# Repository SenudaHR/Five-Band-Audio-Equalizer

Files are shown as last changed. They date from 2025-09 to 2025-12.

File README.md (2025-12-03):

# 🎶 Five Band Audio Equalizer

## 📌 Introduction
An **audio equalizer** is a circuit that adjusts the output of different frequency bands within an audio signal. Equalizers are widely used in hi-fi systems to achieve superior sound quality across the audible spectrum.  

This project implements a **5-band analog audio equalizer** using operational amplifiers and transistors. After splitting the input signal into five distinct frequency ranges, the circuit applies adjustable gain to each band and displays the levels using sound indicators.

---

## Features

- **Five Frequency Bands:** Custom shaping for Bass, Low-Mid, Mid, High-Mid, and Treble ranges.
- **Analog Signal Path:** All audio processing is analog for true fidelity.
- **Visual Level Metering:** LM3915-based LED VU meter for monitoring output.
- **High-Quality Components:** Uses NE5532 op-amps for low noise and high slew rate.

---

## System Overview

- **Band 1:** Sallen-Key unity-gain low band
- **Bands 2–5:** Cascaded MFB band-pass filter stages
- **Amplification:** NE5532 op-amps in all stages
- **Level Display:** LM3915 IC driving a 10-segment LED bar graph

### Block Diagram

```
[Audio In] --> [Sallen-Key Low Band Filter] --> [MFB Band 2] --> [MFB Band 3] --> [MFB Band 4] --> [MFB Band 5] --> [Summing Amp] --> [Audio Out]
                                                  |
                                            [LM3915 LED Display]
```

---

## Bill of Materials (BOM)

| Component | Quantity | Notes |
|---|---|---|
| NE5532 Op-Amp | Varied | Main filter & amplifier stages |
| LM3915 | 5 | LED VU meter |
| Resistors | Varied | See schematic |
| Capacitors | Varied | See schematic |
| Potentiometers| 6 | Band gain controls |
| LED Bars | 5 | Output display |
| PCB/Perfboard | 4 | For circuit assembly |
| Audio Jacks | 2 | Input/Output |
| Power Supply  | 1 | ±12V or as required by op-amps |

---

## Schematics

You can find the circuit diagram, filter specifications, and layout suggestions [`PCB design`].

---

## Assembly Instructions

1. Connect audio input and output jacks.
2. Double-check all connections for shorts and polarity.
3. Power up and test the circuit with a known audio source.

---

## Usage

- Adjust each potentiometer to boost/cut its associated frequency band.
- Monitor the output signal level using the LED display.
- Fine-tune filter frequencies and Q-factors by changing resistor/cap values (see schematic notes).

---

## Troubleshooting

- **No Output:** Check op-amp power pins, input/output jacks, and signal traces.
- **Distorted Sound:** Ensure proper supply voltage and correct filter component values.
- **LED Meter Not Working:** Verify LM3915 wiring and LED polarity.

---

## Contributing

Pull requests and suggestions are welcome! If you identify issues or want improvements, please open an issue or submit a PR.

---

## Author & Contact

Made by [SenudaHR](https://github.com/SenudaHR)  
For questions, contact via GitHub or open an issue.

---

## References

- Data Sheets: [NE5532](https://www.ti.com/lit/ds/symlink/ne5532.pdf) | [LM3915](https://www.ti.com/lit/ds/symlink/lm3915.pdf)
- Audio Equalizer theory: [Wikipedia](https://en.wikipedia.org/wiki/Equalization_(audio))

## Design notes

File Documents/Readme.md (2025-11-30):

Please open presentation.pdf using Adobe Acrobat and download pcb.mp4 and enclosure.mp4 to the same directory

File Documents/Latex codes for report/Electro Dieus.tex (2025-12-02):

\documentclass{article}
\usepackage{titlesec}
\usepackage[utf8]{inputenc}
\usepackage[a4paper, total={6in, 9in}]{geometry}
\usepackage{fancyhdr}
\usepackage{graphicx} % Add the graphicx package
\usepackage{lipsum} % For placeholder text
\usepackage{tikz}

\usepackage[hidelinks]{hyperref}
\usepackage{wrapfig}
\usepackage{acronym}
\usepackage{float}
\usepackage{multicol}
\usepackage{bm}
\usepackage{circuitikz}
\usetikzlibrary{shapes.geometric}
\usepackage{caption}
\usepackage{acronym}
\usepackage{amsmath,amssymb,amsfonts}
\usepackage{algorithmic}
\usepackage{textcomp}
\usepackage{xcolor}
\usepackage[numbers]{natbib}
\bibliographystyle{ieeetran}
\usepackage{url}
% Set up page headers and footers
\pagestyle{fancy}
\fancyhf{}
\rhead{Electro Dieus}
\lhead{\textit{Five Band Audio Equalizer}}
\cfoot{\thepage}

% Redefine the abstract environment to be single column
\renewenvironment{abstract}
{\par\noindent\textbf{\abstractname}\ \ignorespaces}{\par}

% Redefine section format
\titleformat{\section}
{\normalfont\Large\bfseries}{\thesection}{1em}{}

\begin{document}
	
	% Cover Page
	\begin{titlepage}
		
		\centering
		\vspace*{0.5cm}
		 % Replace with the path to your university logo
		\par\vspace{0.02cm}
		{\fontfamily{lmss}
			{\Large Department of Electronic \& Telecommunication Engineering,\\
				University of Moratuwa, Sri Lanka.}}
		\par\vspace{2cm}
		{\LARGE\bfseries Five Band Audio Equalizer\par}
		\vspace{6cm}
		{\large Group Members:\par}
		\begin{tabular}{l l}
			
			230629R	&	Tennakoon U.G.R.B\\
			230548R 	&	Ratnayake R.M.S.H\\
			230613M	&	Shehan M.N.N \\
			230164K	&	Dissanayake R.K.T\\
			
		\end{tabular}\\
		\vspace{1.5cm}
		{Submitted in partial fulfillment of the requirements for the module\par}
		{EN 2091 Laboratory Practice and Projects\par}
		
		\vspace{1.0cm}
		{ Date: \today}
		\vfill
	\end{titlepage}
	
	\newpage
	
	% Abstract
	\begin{abstract}
		\\
		The \textbf{Five Band Audio Equalizer} is an analog signal processing system designed to modify and enhance audio quality by adjusting the amplitude of distinct frequency bands within an audio signal. The system divides the input audio into five specific frequency ranges---20--300~Hz, 300~Hz--1~kHz, 1--4~kHz, 4--10~kHz, and 10--20~kHz---using precision-designed band-pass filters. Each band can be individually amplified or attenuated through a variable gain control stage, enabling users to shape the tonal balance according to preference or acoustic environment. A preamplifier circuit prepares the signal for processing, while a summing amplifier recombines the adjusted frequency bands to produce a clear and balanced output. Additionally, an \ac{LED}-based level display visually indicates the intensity of each band. The system is implemented using operational amplifiers (NE5532) and the LM3915 display driver, ensuring low noise, high fidelity, and efficient visualization. This project demonstrates practical applications of analog circuit design principles, including filter design, signal amplification, \ac{PCB} layout, and system integration for real-world audio enhancement.
		
	\end{abstract}
	\section*{Abbreviations and Acronyms}
	\begin{acronym}
		\acro{PCB}{Printed Circuit Board}
		\acro{Op Amp}{Operational Amplifier}
		\acro{LED}{Light Emitting Diode}
		\acro{MFB}{Multiple Feedback}
	\end{acronym}
	\newpage
	% Table of Contents
	\tableofcontents
	\newpage
	
	% Sections
	\section{Introduction and Functionality}
	An \textbf{audio equalizer} is a fundamental device used in sound systems to balance and adjust the amplitude of specific frequency components within an audio signal. It enables selective amplification or attenuation of chosen frequency ranges, thereby enhancing tonal quality and the overall listening experience. 
	
	In this project, a \textbf{Five Band Audio Equalizer} was developed using analog electronic circuits to divide the incoming audio signal into five distinct frequency bands:
	\begin{itemize}
		\item 20--300~Hz (Bass range)
		\item 300~Hz--1~kHz (Lower midrange)
		\item 1--4~kHz (Upper midrange)
		\item 4--10~kHz (Presence range)
		\item 10--20~kHz (Treble range)
	\end{itemize}
	
	20-300 Hz frequency band is processed using an unity gain Sallen-Key band-pass filter and other frequency bands processed through \ac{MFB} filter to isolate its respective range. The filtered signals then pass through individual \textbf{gain control stages}, allowing users to adjust amplification levels via variable resistors. The processed signals are subsequently recombined using a \textbf{summing amplifier} to produce a customized and balanced output signal.
	
	A \textbf{pre-amplifier} boosts the input audio signal to the required level, while a \textbf{power amplifier} (based on the LM386 IC) drives the final output with sufficient power. Furthermore, a \textbf{\ac{LED} level indicator} circuit, implemented using the LM3915 \ac{LED} display driver, provides real-time visual feedback of the audio levels across frequency bands. 
	
	Overall, this system integrates the concepts of \textbf{analog filtering}, \textbf{amplification}, and \textbf{signal visualization} into a single compact hardware unit, demonstrating the principles of audio signal processing and analog circuit design in a practical and educational context.

	\section{System Architecture}
	
	\begin{figure}[H]
		\centering
		% Resize to fit page width
		\resizebox{\textwidth}{!}{%
			\begin{tikzpicture}[scale=0.4,transform shape]	% Paths, nodes and wires:
				\node[shape=rectangle, draw, line width=1pt, minimum width=3.715cm, minimum height=1.465cm] at (-26.625, 11.75){} node[anchor=center, align=center, text width=3.327cm, inner sep=6pt] at (-26.625, 11.75){\Large Input Signal};
				\node[shape=rectangle, draw, line width=1pt, minimum width=3.715cm, minimum height=1.465cm] at (-20.125, 11.75){} node[anchor=center, align=center, text width=3.327cm, inner sep=6pt] at (-20.125, 11.75){\large Pre-Amplifier};
				\node[shape=rectangle, draw, line width=1pt, minimum width=4.965cm, minimum height=1.465cm] at (-13.5, 21.25){} node[anchor=center, align=center, text width=4.577cm, inner sep=6pt] at (-13.5, 21.25){\large BPF 20 Hz- 300 Hz};
				\node[shape=rectangle, draw, line width=1pt, minimum width=4.965cm, minimum height=1.465cm] at (-13.5, 11.75){} node[anchor=center, align=center, text width=4.577cm, inner sep=6pt] at (-13.5, 11.75){\large BPF 1 kHz- 4 kHz};
				\node[shape=rectangle, draw, line width=1pt, minimum width=4.965cm, minimum height=1.465cm] at (-13.5, 16.5){} node[anchor=center, align=center, text width=4.577cm, inner sep=6pt] at (-13.5, 16.5){\large BPF 300 Hz- 1 kHz};
				\node[shape=rectangle, draw, line width=1pt, minimum width=4.965cm, minimum height=1.465cm] at (-13.5, 7.25){} node[anchor=center, align=center, text width=4.577cm, inner sep=6pt] at (-13.5, 7.25){\Large BPF 4 kHz- 10 kHz};
				\node[shape=rectangle, draw, line width=1pt, minimum width=4.965cm, minimum height=1.465cm] at (-13.5, 2.5){} node[anchor=center, align=center, text width=4.577cm, inner sep=6pt] at (-13.5, 2.5){\Large BPF 10 kHz- 20 kHz};
				\node[shape=rectangle, draw, line width=1pt, minimum width=4.965cm, minimum height=1.465cm] at (-6.75, 21.25){} node[anchor=center, align=center, text width=4.577cm, inner sep=6pt] at (-6.75, 21.25){\Large Gain Controller};
				\node[shape=rectangle, draw, line width=1pt, minimum width=4.965cm, minimum height=1.465cm] at (-6.5, 16.5){} node[anchor=center, align=center, text width=4.577cm, inner sep=6pt] at (-6.5, 16.5){\Large Gain Controller};
				\node[shape=rectangle, draw, line width=1pt, minimum width=4.965cm, minimum height=1.465cm] at (-6.5, 11.75){} node[anchor=center, align=center, text width=4.577cm, inner sep=6pt] at (-6.5, 11.75){\Large Gain Controller};
				\node[shape=rectangle, draw, line width=1pt, minimum width=4.965cm, minimum height=1.465cm] at (-6.5, 7.25){} node[anchor=center, align=center, text width=4.577cm, inner sep=6pt] at (-6.5, 7.25){\Large Gain Controller};
				\node[shape=rectangle, draw, line width=1pt, minimum width=4.965cm, minimum height=1.465cm] at (-6.5, 2.5){} node[anchor=center, align=center, text width=4.577cm, inner sep=6pt] at (-6.5, 2.5){\Large Gain Controller};
				\node[shape=rectangle, draw, line width=1pt, minimum width=3.715cm, minimum height=1.465cm] at (0.5, 11.75){} node[anchor=center, align=center, text width=3.327cm, inner sep=6pt] at (0.5, 11.75){\LARGE Adder};
				\node[shape=rectangle, draw, line width=1pt, minimum width=3.715cm, minimum height=1.465cm] at (6.125, 11.75){} node[anchor=center, align=center, text width=3.327cm, inner sep=6pt] at (6.125, 11.75){\Large Gain Controller};
				\node[shape=rectangle, draw, line width=1pt, minimum width=3.715cm, minimum height=1.465cm] at (11.5, 11.75){} node[anchor=center, align=center, text width=3.327cm, inner sep=6pt] at (11.5, 11.75){\Large Output Singnal};
				\node[shape=ellipse, draw, line width=1pt, minimum width=1.59cm, minimum height=1.215cm](N1) at (-6.675, 23.192){} node[anchor=center] at (N1.text){$\ac{LED}$};
				\node[shape=ellipse, draw, line width=1pt, minimum width=1.59cm, minimum height=1.215cm](N2) at (-6.5, 18.5){} node[anchor=center] at (N2.text){$\ac{LED}$};
				\node[shape=ellipse, draw, line width=1pt, minimum width=1.59cm, minimum height=1.215cm](N3) at (-6.5, 13.75){} node[anchor=center] at (N3.text){$\ac{LED}$};
				\node[shape=ellipse, draw, line width=1pt, minimum width=1.59cm, minimum height=1.215cm](N4) at (-6.575, 9.058){} node[anchor=center] at (N4.text){$\ac{LED}$};
				\node[shape=ellipse, draw, line width=1pt, minimum width=1.59cm, minimum height=1.215cm](N5) at (-6.5, 4.5){} node[anchor=center] at (N5.text){$\ac{LED}$};
				\draw[-latex] (-24.75, 11.75) -- (-22, 11.75);
				\draw[-latex] (-18.25, 11.75) -- (-16, 11.75);
				\draw[-latex] (-17, 11.75) -- (-17, 7.25) -- (-16, 7.25);
				\draw[-latex] (-17, 7.25) -- (-17, 2.5) -- (-16, 2.5);
				\draw[-latex] (-17, 11.75) -- (-17, 16.5) -- (-16, 16.5);
				\draw[-latex] (-17, 16.5) -- (-17, 21.25) -- (-16, 21.25);
				\draw[-latex] (-11, 21.25) -- (-9.25, 21.25);
				\draw[-latex] (-11, 16.5) -- (-9, 16.5);
				\draw[-latex] (-11, 11.75) -- (-9, 11.75);
				\draw[-latex] (-11, 7.25) -- (-9, 7.25);
				\draw[-latex] (-11, 2.5) -- (-9, 2.5);
				\draw[-latex] (-6.5, 3.25) -- (-6.5, 3.75);
				\draw[-latex] (-6.5, 8) -- (-6.5, 8.5);
				\draw[-latex] (-6.5, 12.5) -- (-6.5, 13.125);
				\draw[-latex] (-6.5, 17.25) -- (-6.5, 17.75) -- (-6.5, 17.875);
				\draw[-latex] (-6.75, 22) -- (-6.75, 22.5);
				\draw[-latex] (-4, 11.75) -- (-1.375, 11.75);
				\draw[-latex] (2.375, 11.75) -- (4.25, 11.75);
				\draw[-latex] (8, 11.75) -- (9.625, 11.75);
				\draw (-4, 2.5) -- (-2, 2.5) -- (-2, 11.75);
				\draw (-4, 7.25) -- (-2, 7.25);
				\draw (-4.25, 21.25) -- (-2, 21.25) -- (-2, 11.75);
				\draw (-4, 16.5) -- (-2, 16.5);
			\end{tikzpicture}
		}
		\caption{Functional Block Diagram}
		\label{fig:Functional Block Diagram}
	\end{figure}

	\subsection{Pre-Amplifier Circuit}
	\begin{figure}[H]
		\centering
		% Resize to fit page width
		\resizebox{0.7\textwidth}{!}{%
			\begin{tikzpicture}[scale=0.7, transform shape]

				% Paths, nodes and wires:
				\draw (-17, 12) -- (-5, 12);
				\draw (-11, 12) to[american resistor, l={$100 k\Omega$}] (-11, 8);
				\draw (-11, 8) to[american resistor, l={$100 k\Omega$}] (-11, 5);
				\draw (-14.202, 8.745) to[american resistor, l={$2.2 k\Omega$}] (-10.202, 8.745);
				\draw (-17, 12) to[capacitor, l={$100 nF$}] (-17, 5);
				\draw (-17, 5) -- (-5, 5);
				\draw (-15.5, 8) to[ecapacitor, l={$4.7 \mu F$}] (-15.5, 5);
				\draw (-13.202, 7.755) to[ecapacitor, l={$1 \mu F$}] (-10.202, 7.755);
				\node[op amp, xscale=1.01, yscale=1.01] at (-9, 8.25){};
				\draw (-6.75, 8.25) to[ecapacitor, l={$10 \mu F$}] (-4.5, 8.25);
				\draw (-7.75, 8.25) -- (-6.75, 8.25);
				\draw (-7, 8.25) -| (-7, 10.25) -- (-7.5, 10.25);
				\draw (-9.75, 10.25) -- (-10.25, 10.25) -- (-10.25, 8.75);
				\draw (-14.202, 8.745) -| (-15.5, 8);
				\draw (-13.342, 7.38) to[currtap, l={$In$}] (-13.342, 8.13);
				\draw (-4.5, 8.75) to[currtap, l={$Out$}] (-4.5, 7.75);
				\draw (-4.5, 7.75) -| (-4.5, 5) -- (-5, 5);
				\draw (-9, 8.75) -- (-9, 12);
				\draw (-9, 7.75) -| (-9, 5);
				\node[ground] at (-9.5, 5){};
				\node[circ] at (-15.5, 5){};
				\node[circ] at (-13.342, 4.999){};
				\node[circ] at (-11, 5){};
				\node[circ] at (-9, 5){};
				\node[circ] at (-4.5, 5){};
				\node[circ] at (-9, 12){};
				\node[circ] at (-11, 12){};
				\node[circ] at (-11, 7.75){};
				\node[circ] at (-10.25, 8.75){};
				\node[circ] at (-7, 8.25){};
				\draw (-7.798, 8.25) -- (-7.75, 8.25);
				\node[shape=rectangle, minimum width=1.965cm, minimum height=0.465cm] at (-4.75, 12.5){} node[anchor=north west, align=left, text width=1.577cm, inner sep=6pt] at (-5.75, 12.75){9 - 30 V};
				\draw (-13.342, 7.38) |- (-13.342, 4.999);
				\draw (-9.75, 10.25) to[american resistor, l={$10 k\Omega$}] (-7.5, 10.25);
			\end{tikzpicture}
		}
		\caption{Pre-Amplifier Circuit}
		\label{fig:Pre-Amplifier Circuit}
	\end{figure}
	
	\subsection{Band Pass Filter Design}
	\begin{multicols}{2}

		\begin{figure}[H]
			\centering
			% Resize to fit page width
			\resizebox{0.5\textwidth}{!}{%
				\begin{tikzpicture}[scale=0.9, transform shape]
					% Paths, nodes and wires:
					\node[op amp] at (-9.06, 2.51){};
					\draw (-15.75, 3) to[american resistor, l={$R_{1}$}] (-12.75, 3);
					\draw (-12.75, 3) to[american resistor, l={$R_{3}$}] (-12.75, -1);
					\draw (-10.25, 4.25) to[american resistor, l={$R_{2}$}] (-6.75, 4.25);
					\draw (-12.75, 3) to[capacitor, l={$C$}] (-10.25, 3);
					\draw (-12.75, 5.25) to[capacitor, l={$C$}] (-9.5, 5.25);
					\draw (-12.75, 3) -| (-12.75, 5.25);
					\draw (-10.25, 4.25) -- (-10.5, 4.25) -| (-10.5, 3);
					\draw (-9.5, 5.25) -- (-6.75, 5.25) -| (-6.75, 2.5) |- (-7.87, 2.51);
					\draw (-10.25, 2.02) -| (-11, -1);
					\node[ground] at (-12.75, -1){};
					\node[ground] at (-11, -1){};
					\node[circ] at (-12.75, 3){};
					\node[circ] at (-10.5, 3){};
					\node[circ] at (-6.75, 4.25){};
					\node[circ] at (-6.75, 2.51){};
					\draw (-6.75, 2.5) -- (-6.25, 2.5);
					\node[ocirc](N1) at (-15.75, 3){} node[anchor=east] at ([xshift=-0.02cm]N1.west){$V_{in}$};
					\node[ocirc](N2) at (-6.25, 2.5){} node[anchor=west] at ([xshift=0.08cm]N2.east){$V_{out}$};
				\end{tikzpicture}
				
			}
			\caption{\ac{MFB} Band-Pass filter}
			\label{fig:MFB Band-Pass filter}
		\end{figure}
		
		\begin{itemize}
			\item Mid-frequency: $f_m = \frac{1}{2\pi C}\sqrt{\frac{R_1+R_3}{R_1R_2R_3}}$
			\item Gain at $f_m$: $-A_m = \frac{R_2}{2R_1}$
			\item Filter quality: $Q = \pi f_m R_2 C$
			\item Bandwidth: $B = \frac{1}{\pi R_2 C}$
		\end{itemize}
	\end{multicols}
	
	The \ac{MFB} band-pass allows to adjust Q, $A_m$, and $f_m$ independently. Bandwidth and gain factor do not depend on $R_3$. Therefore, $R_3$ can be used to modify the mid frequency without affecting bandwidth, B, or gain, $A_m$. Furthermore, 

	\begin{center}
		$R_1 = \frac{R_2}{-2A_m}  ,
		R_2 = \frac{Q}{\pi f_m C}  ,
		R_3 = \frac{-A_m R_1}{2Q^2 + A_m} $
	\end{center}
	
	In order to make Fourth-Order Band-Pass filter, we cascaded two \ac{MFB} Band-Pass filters.\\
	The mid frequency of filter 1 is:
	\begin{equation*}
		f_{m1} = \frac{f_m}{\alpha}
	\end{equation*}
	
	the mid frequency of filter 2 is:
	\begin{equation*}
		f_{m2} = f_m \cdot \alpha 
	\end{equation*}

	with $Q$ being the quality factor of the overall filter.
	
	The individual gain ($A_{mi}$) at the partial mid frequencies, $f_{m1}$ and $f_{m2}$, is the same for both filters:
	\begin{equation*}
		A_{mi} = \frac{Q_i}{Q}\sqrt{\frac{A_m}{B_1}}
	\end{equation*}
	
	\subsubsection*{Unity-Gain Sallen-Key Band-Pass Filter (For 20-300 Hz)}
	\begin{figure}[H]
		\centering
		% Resize to fit page width
		\resizebox{0.9\textwidth}{!}{%
			
			\begin{tikzpicture}[scale=0.6, transform shape]
				% Paths, nodes and wires:
				\node[op amp, yscale=-1] at (-14.81, 4.49){};
				\node[op amp, yscale=-1] at (-6.81, 3.99){};
				\draw (-20, 5) to[american resistor, l={$R_2$}] (-16, 4.98);
				\draw (-19.5, 5) to[american resistor, l={$R_1$}] (-22, 5);
				\draw (-10, 6.5) to[american resistor, l={$R_2^*$}] (-6, 6.5);
				\draw (-9, 4.5) to[american resistor, l={$R_1^*$}] (-9, 0.75);
				\draw (-17.5, 6.5) to[capacitor, l={$C_2$}] (-14.25, 6.5);
				\draw (-16.75, 4) to[capacitor, l={$C_1$}] (-16.75, 1);
				\draw (-13.62, 4.49) to[capacitor, l={$C$}] (-11.25, 4.5);
				\draw (-11.25, 4.5) to[capacitor, l={$C$}] (-9, 4.5);
				\draw (-9, 4.5) -- (-8, 4.5);
				\draw (-11.25, 4.5) -| (-11, 6.5) -- (-10, 6.5);
				\draw (-6, 6.5) -- (-4.75, 6.5) -| (-4.75, 4) |- (-5.62, 3.99);
				\draw (-8, 3.5) -- (-8.25, 3.5) -| (-8.25, 2.25) -| (-4.75, 3.99);
				\draw (-19, 5) -| (-19, 6.5) -- (-17.5, 6.5);
				\draw (-14.25, 6.5) -| (-13.5, 4.5);
				\draw (-16, 4) |- (-16.25, 4) -| (-16.25, 3.25) -- (-13.5, 3.25) -| (-13.5, 4.5);
				\draw (-16.75, 4) -| (-16.75, 5);
				\node[ground] at (-16.75, 1){};
				\node[ground] at (-9, 1){};
				\node[circ] at (-19, 5){};
				\node[circ] at (-16.75, 5){};
				\node[circ] at (-13.5, 4.5){};
				\node[circ] at (-11, 4.5){};
				\node[circ] at (-9, 4.5){};
				\node[circ] at (-4.75, 4){};
				\node[ocirc](N1) at (-22, 5){} node[anchor=east] at (N1.west){$V_{in}$};
				\node[ocirc](N2) at (-3.75, 4){} node[anchor=west] at (N2.east){$V_{out}$};
				\draw (-4.75, 3.99) -| (-3.75, 4);
			\end{tikzpicture}
		}
		\caption{Unity-Gain Sallen-Key Band-Pass Filter}
		\label{fig:Unity-Gain Sallen-Key Band-Pass Filter}
	\end{figure}
	
	{For	given $C_1$ and $C_2$, the resistor values for $R_1$ and $R_2$ are calculated through:
		\[
		R_{1,2} = \frac{a_1 C_2 \mp \sqrt{a_1^2 C_2^2 - 4 b_1 C_1 C_2}}{4 \pi f_c C_1 C_2}
		\]
		For	given $C$, the resistor values for $R_1^*$ and $R_2^*$ are calculated through:
		\[
		R_1^* = \frac{1}{\pi f_c C a_1}
		,
		R_2^* = \frac{a_1}{4 \pi f_c C b_1}	\]}
	
	\subsubsection*{Calculated Theoretical Resistor \& Capacitor Values for Band-pass Filters\footnote{See Appendix \ref{app:practical values} for practical resistor \& capacitor values.}}
	
	\begin{table}[h!]
		\centering
		
		\begin{tabular}{|c|c|c|c|c|c|c|}
			\hline
			$R_1$ & $R_2$ & $C_1$ & $C_2$ &$R_1^*$ & $R_2^*$ & $C$ \\
			\hline
			1.2 k$\Omega$ & 2.2 k$\Omega$ & 220 nF & 470 nF &47 k$\Omega$ & 27 k$\Omega$ & 220 nF \\
			\hline
		\end{tabular}
		\caption{Resistor and Capacitor values (20 Hz – 300 Hz)}
	\end{table}
	\begin{table}[h!]
		\centering
		
		\begin{tabular}{|c|c|c|c|c|}
			\hline
			Frequency Range & $R_1$ & $R_2$ & $R_3$ & $C$ \\
			\hline
			300 Hz – 1 kHz   & 3.3 k$\Omega$ & 10 k$\Omega$ & 3.9 k$\Omega$ & 100 nF \\
			1 kHz – 4 kHz    & 2.7 k$\Omega$ & 8.2 k$\Omega$ & 6.8 k$\Omega$ & 33 nF \\
			4 kHz – 10 kHz   & 2.2 k$\Omega$ & 6.8 k$\Omega$ & 1 k$\Omega$   & 15 nF \\
			10 kHz – 20 kHz  & 2.2 k$\Omega$ & 5.6 k$\Omega$ & 390 $\Omega$  & 10 nF \\
			\hline
		\end{tabular}
		\caption{Resistor and Capacitor values for 1st \ac{MFB} Filter}
	\end{table}
	
	\begin{table}[h!]
		\centering
		
		\begin{tabular}{|c|c|c|c|c|}
			\hline
			Frequency Range & $R_1$ & $R_2$ & $R_3$ & $C$ \\
			\hline
			300 Hz – 1 kHz   & 15 k$\Omega$ & 47 k$\Omega$ & 15 k$\Omega$ & 10 nF \\
			1 kHz – 4 kHz    & 3.3 k$\Omega$ & 10 k$\Omega$ & 6.8 k$\Omega$ & 10 nF \\
			4 kHz – 10 kHz   & 2.7 k$\Omega$ & 8.2 k$\Omega$ & 1 k$\Omega$   & 6.8 nF \\
			10 kHz – 20 kHz  & 1.8 k$\Omega$ & 5.6 k$\Omega$ & 330 $\Omega$  & 6.8 nF \\
			\hline
		\end{tabular}
		\caption{Resistor and Capacitor values for 2nd \ac{MFB} Filter}
	\end{table}

	\subsection{Gain Controller}
	\noindent
	\begin{minipage}{0.48\textwidth}
		\centering
		\begin{circuitikz}
			% Op-amp
			\node[op amp] (opamp) at (0.44, 4.49) {};
			
			% Input resistor
			\draw (-4.5, 5) to[american resistor, l={$R$}] (-0.38, 4.98);
			
			% Feedback resistor (variable)
			\draw (-0.75, 6.25) to[variable american resistor, l={$kR$}] (2.25, 6.25);
			
			% Feedback wiring
			\draw (-0.75, 6.25) -- (-1, 6.25) -| (-1, 5);
			\draw (-0.75, 4) -- (-1, 4) -| (-1, 2.75);
			
			% Output connection
			\draw (1.63, 4.49) -| (2.5, 4.5) -- (2.5, 6.25) -- (2.25, 6.25);
			
			% Input/output nodes
			\node[ocirc](N1) at (-4.5, 5){} node[anchor=east] at (N1.west){$V_{in}$};
			\draw (2.5, 4.49) -| (2.75, 4.5);
			\node[ocirc](N2) at (2.75, 4.49){} node[anchor=west] at (N2.east){$V_{out}$};
			
			% Ground and connection dots
			\node[circ] at (-1, 5) {};
			\node[circ] at (2.5, 4.5) {};
			\node[ground] at (-1, 2.75) {};
		\end{circuitikz}
		\captionof{figure}{Gain Controller}
		\label{fig:GainController}
	\end{minipage}%
	\hfill
	\begin{minipage}{0.48\textwidth}
		\[
		\frac{V_{in}-0}{R} = \frac{0 - V_{out}}{kR}
		\]
		\[
		V_{out} = -kV_{in}
		\]
	\end{minipage}
	\subsection{Adder \& Gain Controller}
	\noindent
	\begin{minipage}{0.48\textwidth}
		\centering
		\begin{circuitikz}[scale=0.9,transform shape]
			% Paths, nodes and wires:
			\node[op amp] at (0.44, 4.49){};
			\draw (-0.75, 6.25) to[variable american resistor, l={$kR$}] (2.25, 6.25);
			\draw (-0.75, 6.25) -- (-1, 6.25) -| (-1, 5);
			\draw (-0.75, 4) -- (-1, 4) -| (-1, 2.75);
			\draw (1.63, 4.49) -| (2.5, 4.5) -- (2.5, 6.25) -- (2.25, 6.25);
			\draw (2.5, 4.49) -| (2.75, 4.5);
			\node[ocirc](N1) at (2.75, 4.49){} node[anchor=west] at (N1.east){$V_{out}$};
			\node[circ] at (-1, 5){};
			\node[circ] at (2.5, 4.5){};
			\node[ground] at (-1, 2.75){};
			\draw (-0.75, 4.98) |- (-1, 5) -- (-1.75, 5) -- (-2.5, 5) -| (-2.5, 6.5) -- (-2.5, 3.25);
			\draw (-6, 6.5) to[american resistor, l={$R$}] (-2.5, 6.5);
			\draw (-6, 5.5) to[american resistor, l={$R$}] (-2.5, 5.5);
			\draw (-6, 4.5) to[american resistor, l={$R$}] (-2.5, 4.5);
			\draw (-6, 3.5) to[american resistor, l={$R$}] (-2.5, 3.5);
			\draw (-6, 2.5) to[american resistor, l={$R$}] (-2.5, 2.5);
			\draw (-2.5, 3.25) -| (-2.5, 2.5);
			\node[ocirc](N2) at (-6, 6.5){} node[anchor=east] at (N2.west){$V_1$};
			\node[ocirc](N3) at (-6, 5.5){} node[anchor=east] at (N3.west){$V_2$};
			\node[ocirc](N4) at (-6, 4.5){} node[anchor=east] at (N4.west){$V_3$};
			\node[ocirc](N5) at (-6, 3.5){} node[anchor=east] at (N5.west){$V_4$};
			\node[ocirc](N6) at (-6, 2.5){} node[anchor=east] at (N6.west){$V_5$};
			\node[circ] at (-2.5, 5.5){};
			\node[circ] at (-2.5, 4.5){};
			\node[circ] at (-2.5, 3.5){};
		\end{circuitikz}
		
		\captionof{figure}{Adder and Gain Controller}
		\label{fig:Adder and Gain Controller}
	\end{minipage}%
	\hfill
	\begin{minipage}{0.4\textwidth}
		
		\[ \sum_{i=1}^{5} \frac{V_i-0}{R} = \frac{0-V_{out}}{kR}
		\]
		\[V_{out}=-k\sum_{i=1}^{5} V_{i}
		\]
		
	\end{minipage}
	
	\subsection{\ac{LED} Display}
	
	\begin{figure}[H]
		\centering
		
		\caption{Circuit connection for \ac{LED} display}
		\label{fig:led}
	\end{figure}
	
	\subsection{Power Amplifier Circuit}
	\begin{figure}[H]
		\centering
		% Resize to fit page width
		\resizebox{0.9\textwidth}{!}{%
			\begin{tikzpicture}[scale=0.6, transform shape]
				% Paths, nodes and wires:
				% Paths, nodes and wires:
				\node[op amp, xscale=1.55, yscale=-1.55](N1) at (-6.156, 4.509){} node[anchor=center] at (N1.text){$LM386$};
				\draw (1, 4.5) to[loudspeaker, l={8 $\Omega$, 0.5 W}] (1, 2.25);
				\draw (-12, 6.75) to[american resistor] (-12, 3.75);
				\draw (-3, 4.5) to[american resistor, l={$10\Omega$}] (-3, 2);
				\draw (-6.285, 7.845) to[american resistor, l={$1.2 k\Omega$}] (-6.285, 5.345);
				\draw (-3, 2) to[capacitor, l={$100 nF$}] (-3, 0);
				\draw (-5.285, 6.595) to[ecapacitor, l={$10\mu F$}] (-5.285, 4.845);
				\draw (-2.5, 4.5) to[ecapacitor, l={$220 \mu F$}] (-0.25, 4.5);
				\draw (-12, -0) -- (1, -0) -| (1, 2.25);
				\draw (1, 4.5) -- (-0.25, 4.5);
				\draw (-2.5, 4.5) |- (-4.311, 4.51);
				\draw (-6.285, 7.845) -- (-5.285, 7.845) -| (-5.285, 6.595);
				\draw (-7, 5.75) -| (-7, 8);
				\draw (-7, 3.25) -| (-7, -0);
				\draw (-8, 3.75) -| (-8, -0);
				\draw (-12, 6.75) -- (-13, 6.75);
				\draw (-12, 3.75) -| (-12, -0);
				\node[ground] at (-7, -0){};
				\draw[-latex] (-8, 5.269) -- (-12, 5.269);
				\node[ocirc](N2) at (-13, 6.75){} node[anchor=east] at (N2.west){$Input$};
				\node[ocirc] at (-13, -0){};
				\node[circ] at (-12, -0){};
				\node[circ] at (-8, -0){};
				\node[circ] at (-7, -0){};
				\node[circ] at (-3, -0){};
				\node[circ] at (-3, 4.5){};
				\node[plain crossing](N3) at (-7, 8){} node[anchor=south] at (N3.north){$+ V_{CC}$};
				\draw (-12, -0) -- (-13, -0);
				\node[ocirc](N4) at (-6.285, 5.345){} node[anchor=north] at (N4.south){$1$};
				\node[ocirc](N5) at (-5.25, 4.75){} node[anchor=east] at (N5.text){$8$};
				\draw (-5.267, 4.692) -| (-5.285, 4.845);
			\end{tikzpicture}
		}
		\caption{Power Amplifier Circuit}
		\label{fig:Power Amplifier Circuit}
	\end{figure}

	\section{Component Selection (Main electronic components)}
	
	\begin{enumerate}
		\item\textbf{NE5532 Operational Amplifier}
		\begin{itemize}
			
			\item \textbf{Low Noise}: 5\,nV/$\sqrt{\text{Hz}}$ suitable for high-fidelity audio
			\item \textbf{Bipolar Input}: Ensures low offset and distortion in precision audio
			\item \textbf{Dual Channel}: Two \ac{Op Amp} per IC for compact design
			\item \textbf{High Slew Rate}: 9\,V/$\mu$s supports wide dynamic range
			\item \textbf{Wide Bandwidth}: 10\,MHz gain-bandwidth product for audio applications
			\item \textbf{Wide Supply}: $\pm3$\,V to $\pm20$\,V operation for design flexibility
			\item \textbf{High Drive Capability}: Can directly drive 600\,$\Omega$ loads
		\end{itemize}
		\item \textbf{LM3915 Dot/Bar Display Driver}
		\begin{itemize}
			\item Logarithmic 3 dB/step response for audio
			\item Direct \ac{LED} drive without current-limiting resistors
			\item Simple setup with minimal external components
			\item Over-voltage protection ($\pm$35V) on input
		\end{itemize}

	\end{enumerate}	

	\begin{minipage}[t]{0.48\textwidth}
		\centering
		
		\captionof{figure}{NE5532P Operational Amplifier}
	\end{minipage}
	\hfill
	\begin{minipage}[t]{0.48\textwidth}
		\centering
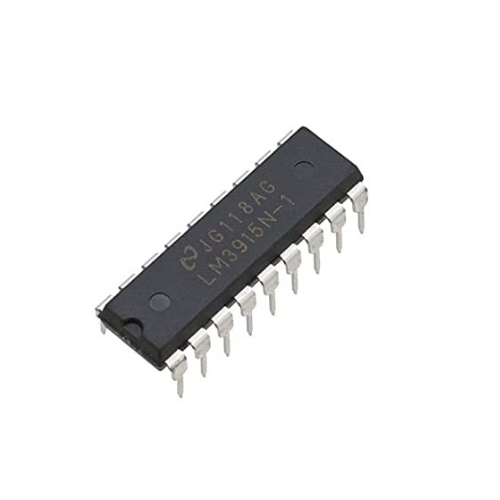
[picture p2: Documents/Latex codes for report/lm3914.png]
		
		\captionof{figure}{LM3915 Dot/Bar Display Driver}
	\end{minipage}

	\section{\ac{PCB} Design}
	We designed 4 separate \ac{PCB}s using Altium Designer. (Why 4 \ac{PCB}s?\footnote{See Appendix \ref{app:PCB Schematics}.})
	\begin{multicols}{2}
		\begin{figure}[H]
			\centering
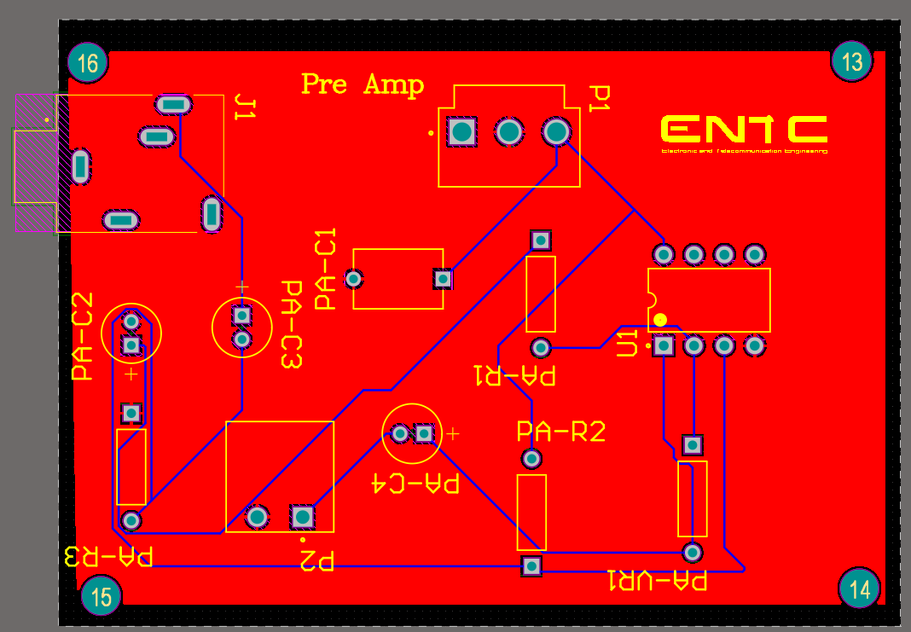
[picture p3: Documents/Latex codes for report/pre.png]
			
			\caption{2D pathway of Pre Amplifier Circuit}
			\label{fig:pre}
		\end{figure}
		\begin{figure}[H]
			\centering
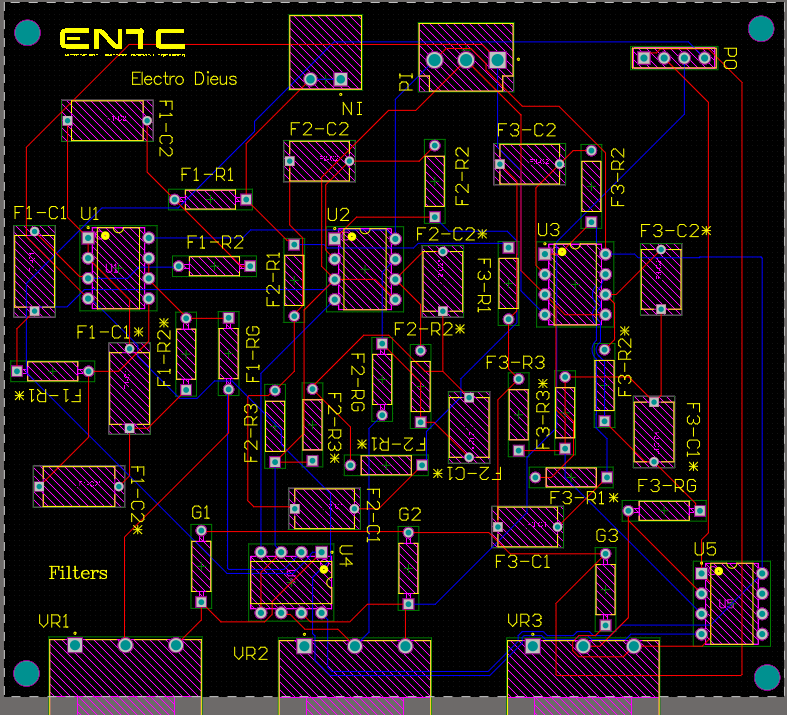
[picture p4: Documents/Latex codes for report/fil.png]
			
			\caption{2D pathway of Filter Circuit}
			\label{fig:fil}
		\end{figure}
		\begin{figure}[H]
			\centering
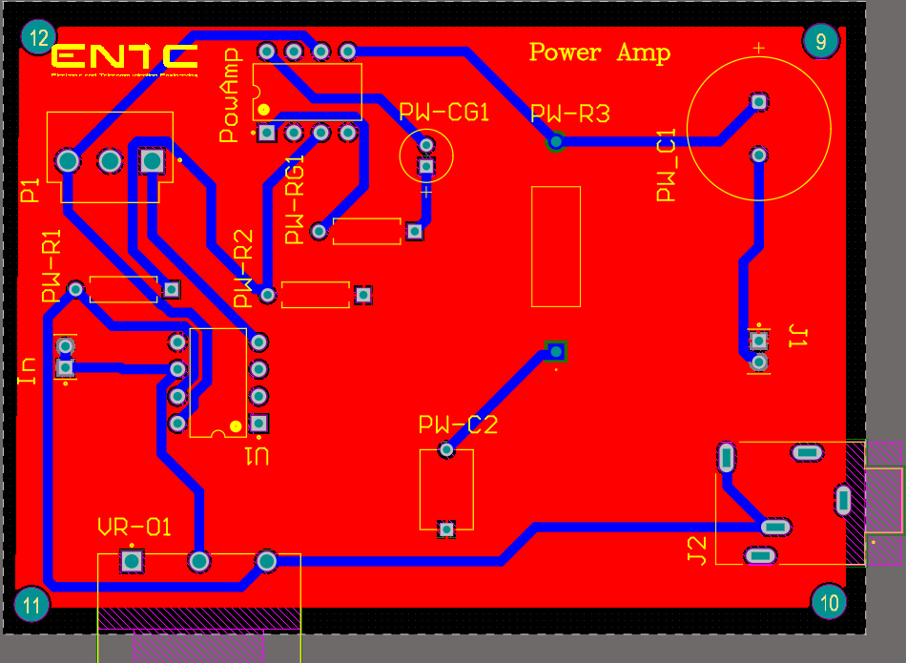
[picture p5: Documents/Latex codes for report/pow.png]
			
			\caption{2D pathway of Power Amplifier Circuit}
			\label{fig:pow}
		\end{figure}
		\begin{figure}[H]
			\centering
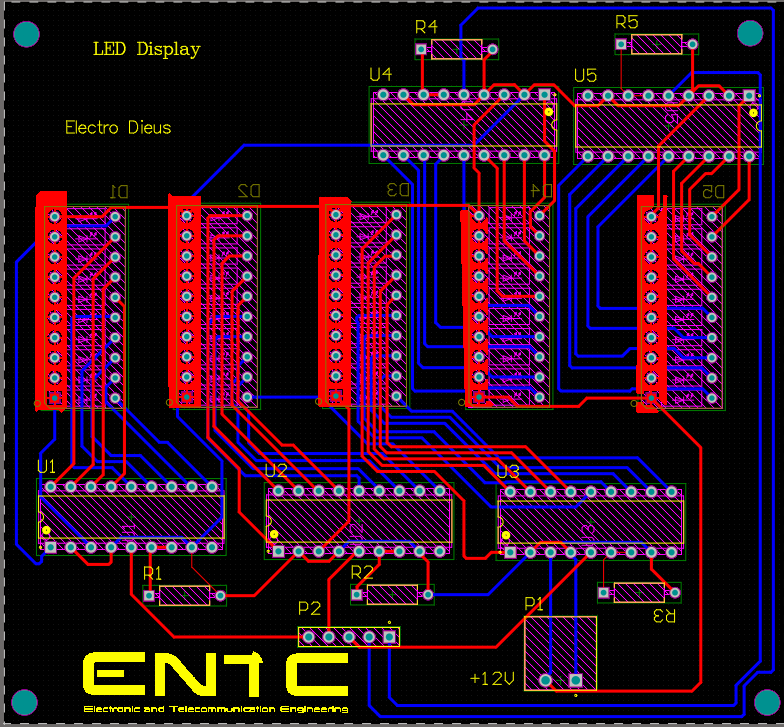
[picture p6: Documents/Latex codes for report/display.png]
			
			\caption{2D pathway of \ac{LED} Display Circuit}
			\label{fig:display}
		\end{figure}
		
	\end{multicols}
	\begin{figure}[H]
		\centering
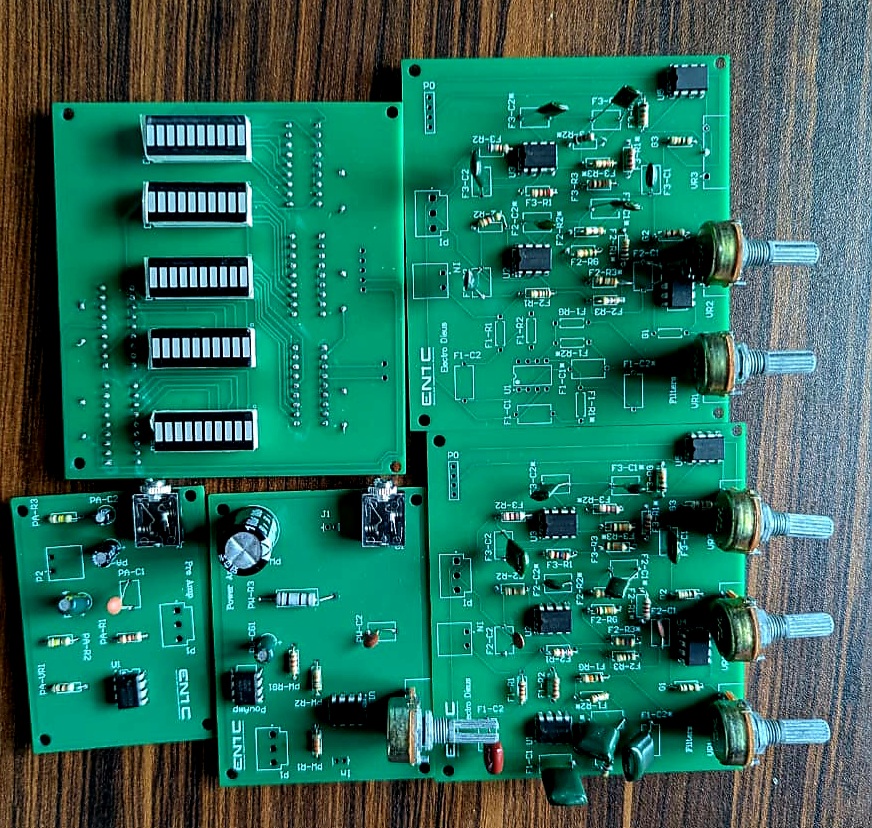
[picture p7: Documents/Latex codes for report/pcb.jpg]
		
		\caption{Soldered \ac{PCB}s}
		\label{fig:pcb}
	\end{figure}

	\section{Enclosure Design}
	
	\begin{multicols}{2}
		\begin{figure}[H]
			\centering
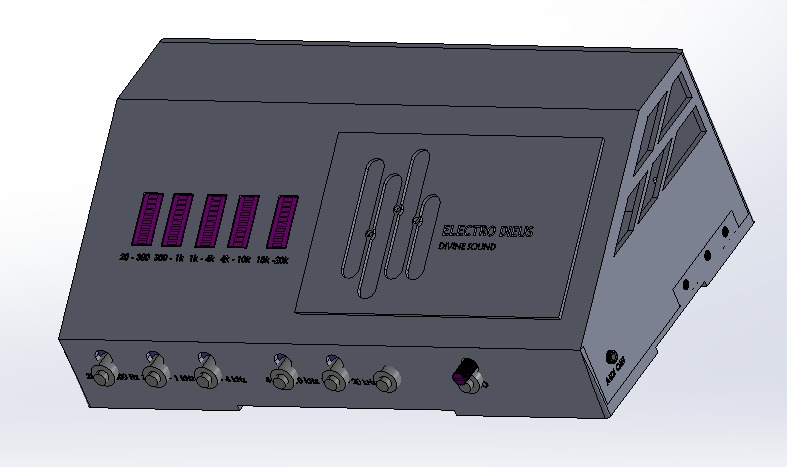
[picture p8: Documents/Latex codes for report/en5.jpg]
			
			\caption{Enclosure front view}
			\label{fig:Enclosure front view}
		\end{figure}
		\begin{figure}[H]
			\centering
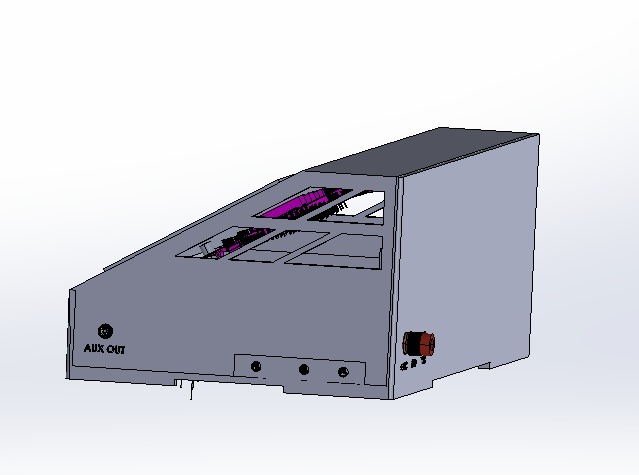
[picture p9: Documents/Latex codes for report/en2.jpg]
			
			\caption{Right side view}
			\label{fig:Side view1}
		\end{figure}
		\begin{figure}[H]
			\centering
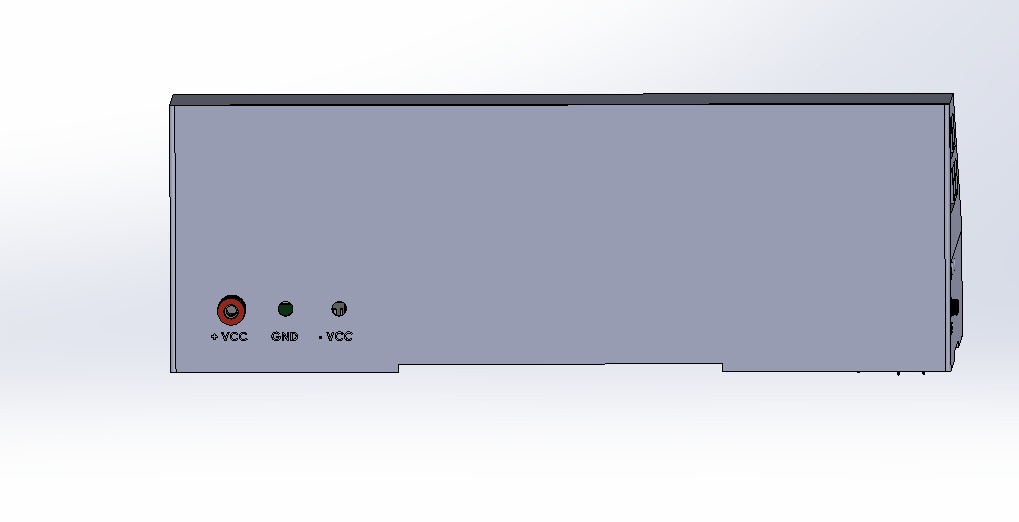
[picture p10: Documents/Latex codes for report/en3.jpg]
			
			\caption{Back view}
			\label{fig:Back view}
		\end{figure}
		\begin{figure}[H]
			\centering
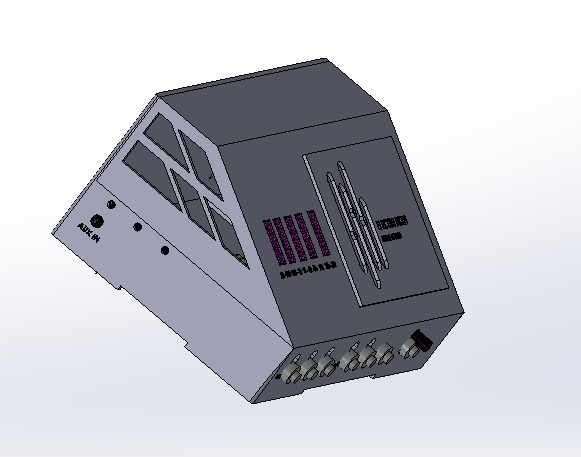
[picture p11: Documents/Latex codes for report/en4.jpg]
			
			\caption{Left side view}
			\label{fig:Left side view}
		\end{figure}
	\end{multicols}
    \begin{figure}[H]
        \centering
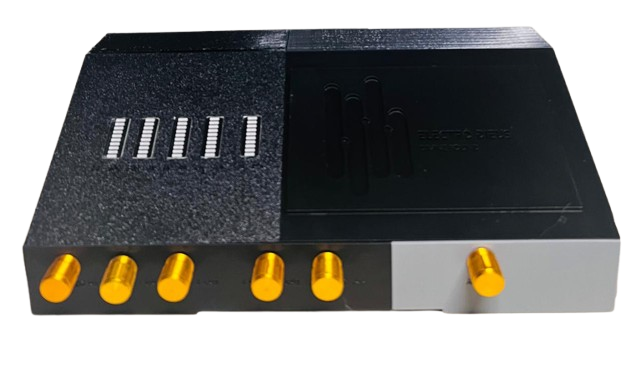
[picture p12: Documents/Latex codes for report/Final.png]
        
        \caption{Final product}
        \label{fig:placeholder}
    \end{figure}
	
	\newpage
	\section{Software Simulation and Hardware Testing}
	\subsection{Software Simulation (Using LTspice)}
	
	\begin{figure}[H]	\centering
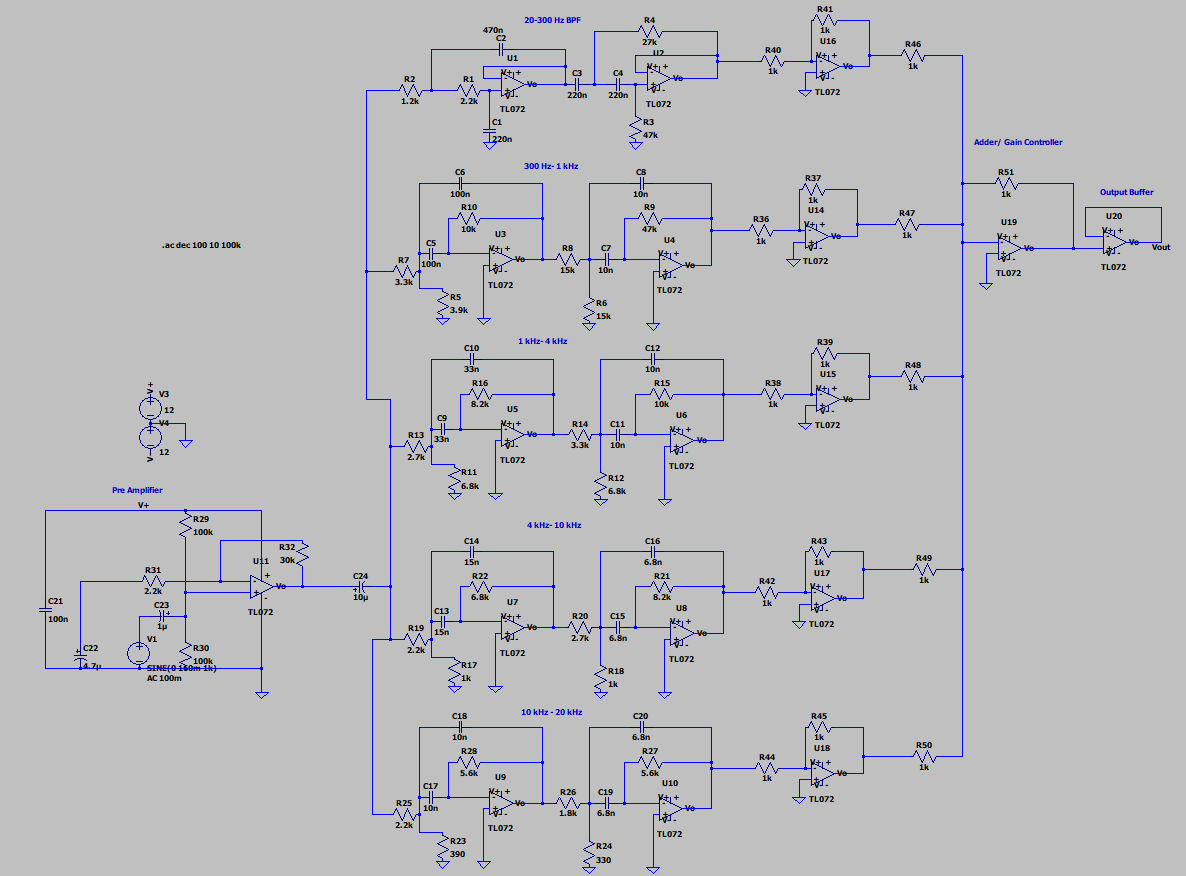
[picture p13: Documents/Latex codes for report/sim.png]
		
		\caption{Circuit Diagram}
		\label{fig:sim}
	\end{figure}
	\begin{figure}[H]
		\centering
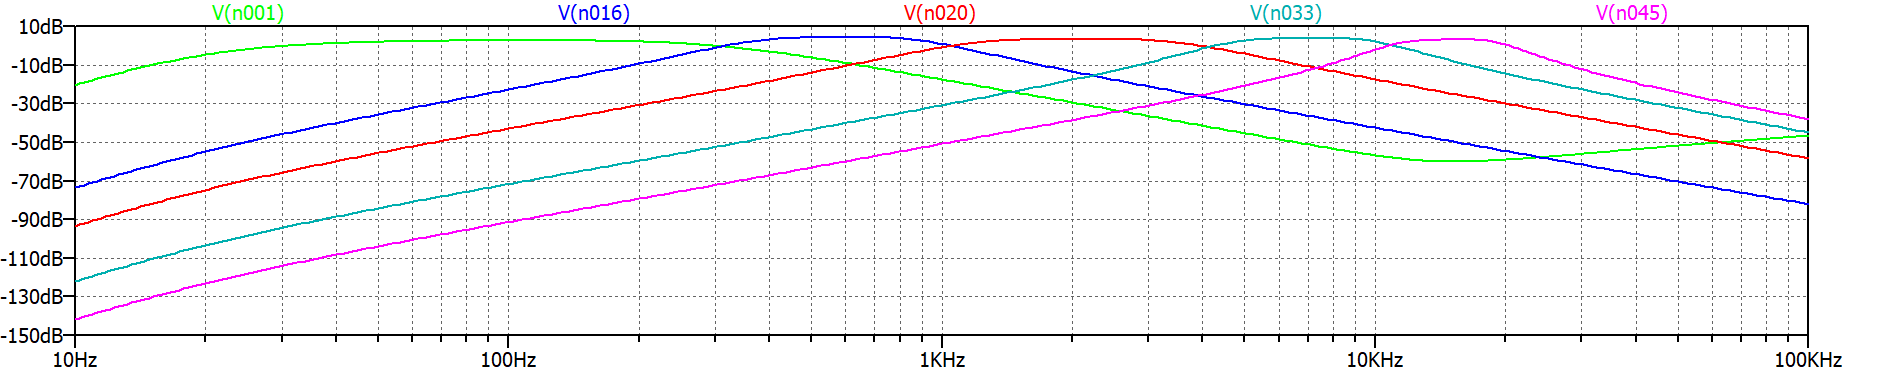
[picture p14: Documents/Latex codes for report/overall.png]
		
		\caption{Frequency Response of Each Filter}
		\label{fig:Frequency Response of Each Filter}
	\end{figure}
	\begin{figure}[H]
	
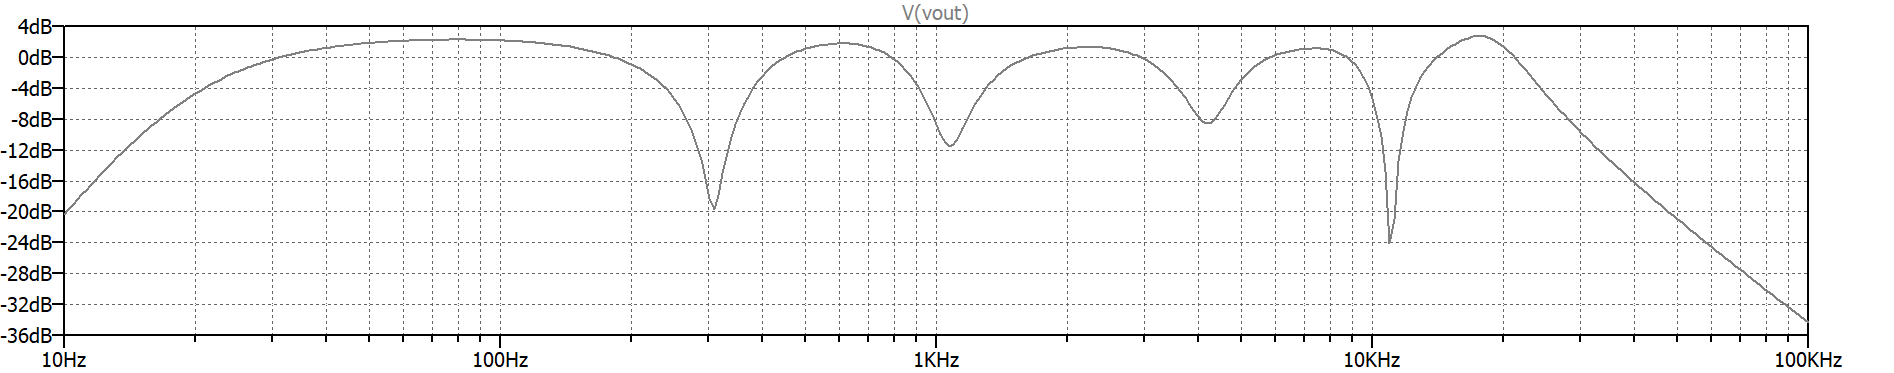
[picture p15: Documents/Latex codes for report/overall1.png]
		
		\caption{Overall Frequency Response}
		\label{fig:overall1}
	\end{figure}

	\subsection{Hardware Testing}
	\begin{multicols}{2}
		\begin{figure}[H]
			\centering
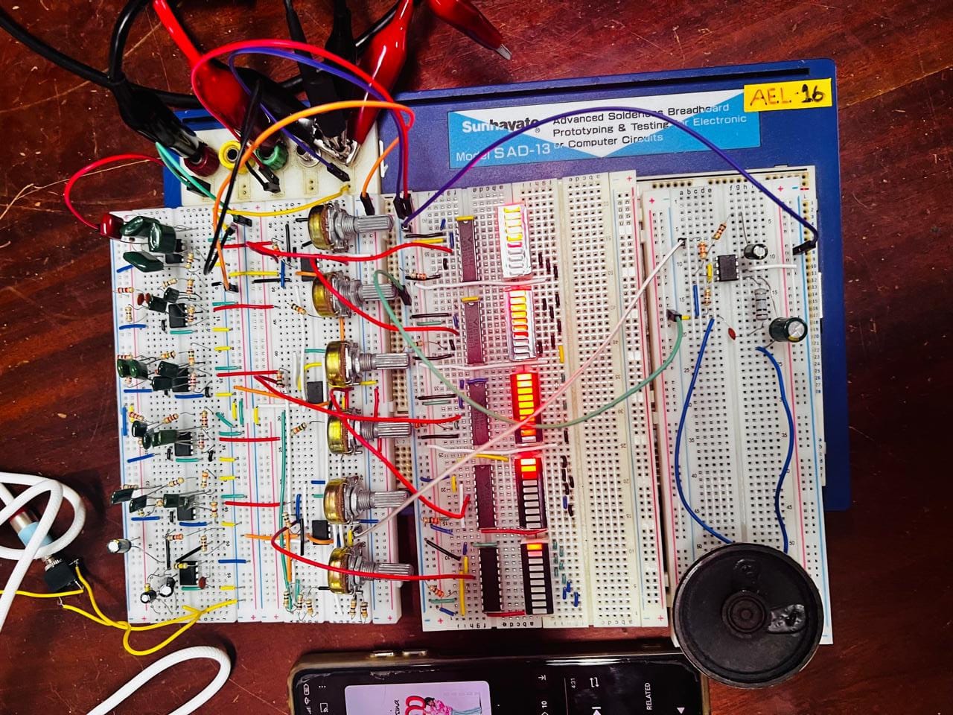
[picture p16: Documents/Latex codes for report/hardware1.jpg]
			
			\caption{Breadboard implementation}
			\label{fig:hardware}
		\end{figure}
		\begin{figure}[H]
			\centering
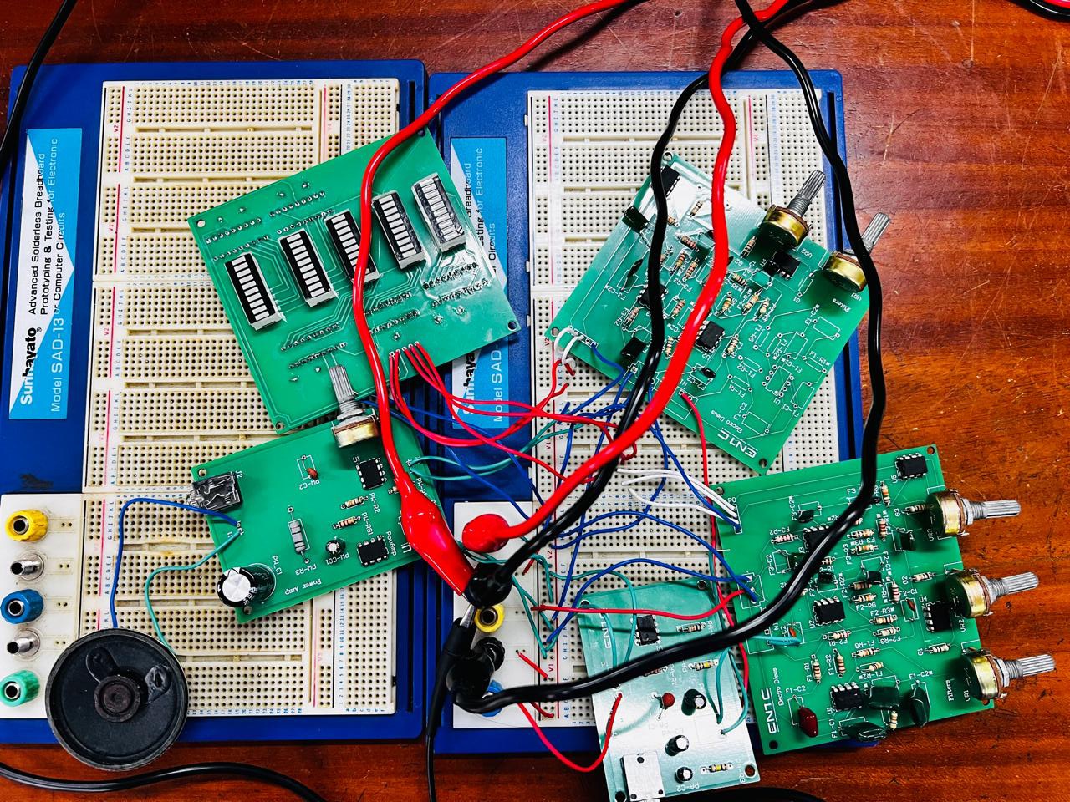
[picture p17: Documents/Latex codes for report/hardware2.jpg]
			
			\caption{\ac{PCB} testing}
			\label{fig:harware2}
		\end{figure}
	\end{multicols}

	\section{Conclusion \& Future Works}
	The \textbf{Five Band Audio Equalizer} successfully achieves its primary objective of dividing an input audio signal into five distinct frequency bands and allowing individual gain control for each band. Through the integration of pre-amplifier, band-pass filter, gain control, adder, and power amplifier stages, the system provides a fully analog audio equalization platform with real-time visual feedback using an \ac{LED} display. The implemented filters effectively cover the entire audible range from 20~Hz to 20~kHz, enabling fine-tuned tonal adjustment and improved sound clarity. Experimental testing confirmed that the circuit delivers stable operation with low distortion and noise, demonstrating the effectiveness of the NE5532 \ac{Op Amp} and LM3915 \ac{LED} display driver in high-fidelity analog applications.
	
	\textbf{Future development} of the project can focus on several enhancements. Firstly, the system can be expanded into a \textbf{stereo equalizer} by duplicating the current design for left and right audio channels, enabling complete two-channel sound processing for improved spatial audio experience. Secondly, designing a dedicated \textbf{power supply unit} with voltage regulation and filtering will ensure stable performance and minimize noise interference. Additional improvements could include integrating tone presets, miniaturized \ac{PCB} layouts, and incorporating protection circuits to increase durability and user convenience. These developments would transform the prototype into a fully functional and reliable consumer-grade audio equalizer system.

	\section{Contribution of Group Members}
	\begin{tabular}{|l|p{9cm}|} % p{6cm} allows auto line wrapping
		\hline
		\textbf{Student's Name (Index No.)} & \textbf{Contribution} \\
		\hline
		Tennakoon U.G.R.B. (230629R) & Filter calculations, \ac{PCB} design, Testing \& debugging, Soldering \\
		\hline
		Ratnayake R.M.S.H. (203548R) & \ac{PCB} design, Circuits design, Circuits simulation, Soldering \\
		\hline
		Shehan M.N.N. (230613M) & Breadboard implementation, Enclosure Design, Testing \\
		\hline
		Dissanayake R.K.T. (230164K) &  \ac{LED} display circuit design \& breadboard implementation, Testing, Assembling \\
		\hline
	\end{tabular}

	\section*{Acknowledgment}
	
	We would like to express our sincere gratitude to \textbf{Mr. Chanula Luckshan}, our project supervisor, for his continuous guidance and support throughout the development of the \textit{Five Band Audio Equalizer} project. His valuable suggestions at the early stages of circuit design and his assistance in identifying and correcting errors during \ac{PCB} and enclosure design were instrumental in achieving a successful outcome.
	
	We also wish to extend our appreciation to \textbf{Dr. Pranjeevan Kulasingham}, our Signals and Systems lecturer, for providing us with a comprehensive understanding of analog filter design principles, which formed the foundation for our filter implementation in this project.
	
	Our heartfelt thanks go to \textbf{Dr. Sampath Perera}, the module coordinator of EN2091 Laboratory Practice and Projects, for his overall supervision, encouragement, and for providing the necessary resources to complete this project effectively.
	
	Finally, we would like to acknowledge the support of all the \textbf{laboratory assistants} of the Department of Electronic and Telecommunication Engineering for their technical help, timely guidance, and assistance during the hardware testing and implementation stages.
	
	\begin{thebibliography}{1}
		\bibitem{TI2002}
		Texas Instruments, \emph{op Amps for Everyone Design Guide}, Rev. 8, Advanced Analog Products, SLOD006B, Aug. 2002. [Online]. Available: https://web.mit.edu/6.101/www/reference/op\_amps\_everyone.pdf
		
		\bibitem{TI:NE5532}
		Texas Instruments, “NE5532 — Dual, 30-V, 10-MHz, low-noise operational amplifier for audio applications,”  
		TI product page (Datasheet Rev. J), Jan. 27, 2015.  
		[Online]. Available: \url{https://www.ti.com/product/NE5532}  
		\bibitem{lm3915_datasheet}
		Texas Instruments. \emph{LM3915 Dot/Bar Display Driver Datasheet}, SNVS740C. Revised Mar. 2013. [Online]. Available: \url{https://www.alldatasheet.com/datasheet-pdf/view/558236/TI/LM3915.html}
		
		\bibitem{HomemadeCircuitsOpAmp}
		``Op Amp Preamplifier Circuits – For MICs, Guitars, Pick-ups, Buffers." \emph{Homemade Circuits}. Last Updated: Sept. 13, 2023. Available: \url{https://www.homemade-circuits.com/op-amp-preamplifier-circuits-for-mics-guitars-pick-ups-as-buffer/} 
		
		\bibitem{GaraipoomLM386}
		A. Garaipoom, ``LM386 Audio Amp Circuit – Build Small, Loud \& Battery-Friendly!," \emph{ElecCircuit.com}. Last Updated: Sept. 17, 2025. Available: \url{https://www.eleccircuit.com/lm386-audio-amplifier-circuit/} 
	\end{thebibliography}
	
	\newpage
	\section*{Appendix}
	\appendix
	
	\section{Practical Resistor \& Capacitor Values}\label{app:practical values}
	
	\begin{table}[h!]
		\centering
		
		\begin{tabular}{|c|c|c|c|c|c|c|}
			\hline
			$R_1$ & $R_2$ & $C_1$ & $C_2$ &$R_1^*$ & $R_2^*$ & $C$ \\
			\hline
			1.2 k$\Omega$ & 2.2 k$\Omega$ & 220 nF & 470 nF &47 k$\Omega$ & 27 k$\Omega$ & 220 nF \\
			\hline
		\end{tabular}
		\caption{Resistor and Capacitor values (20 Hz – 300 Hz)}
	\end{table}
	\begin{table}[h!]
		\centering
		
		\begin{tabular}{|c|c|c|c|c|}
			\hline
			\textbf{Frequency Range} & $R_1$ & $R_2$ & $R_3$ & $C$ \\ \hline
			300 Hz -- 1 kHz   & $2.7\,\text{k}\Omega$ & $10\,\text{k}\Omega$ & $10\,\text{k}\Omega$ & $100\,\text{nF}$ \\ \hline
			1 kHz -- 4 kHz    & $2.7\,\text{k}\Omega$ & $8.2\,\text{k}\Omega$ & $15\,\text{k}\Omega$ & $33\,\text{nF}$ \\ \hline
			4 kHz -- 10 kHz   & $2.2\,\text{k}\Omega$ & $6.8\,\text{k}\Omega$ & $1.2\,\text{k}\Omega$ & $15\,\text{nF}$ \\ \hline
			10 kHz -- 20 kHz  & $1.8\,\text{k}\Omega$ & $5.6\,\text{k}\Omega$ & $470\,\Omega$ & $10\,\text{nF}$ \\ \hline
		\end{tabular}
		\caption{Resistor and Capacitor values for 1st \ac{MFB} Filter}
	\end{table}
	\begin{table}[h!]
		\centering
		
		\begin{tabular}{|c|c|c|c|c|}
			\hline
			\textbf{Frequency Range} & $R_1$ & $R_2$ & $R_3$ & $C$ \\ \hline
			300 Hz -- 1 kHz   & $8.2\,\text{k}\Omega$ & $27\,\text{k}\Omega$ & $27\,\text{k}\Omega$ & $10\,\text{nF}$ \\ \hline
			1 kHz -- 4 kHz    & $2.2\,\text{k}\Omega$ & $8.2\,\text{k}\Omega$ & $15\,\text{k}\Omega$ & $10\,\text{nF}$ \\ \hline
			4 kHz -- 10 kHz   & $2.2\,\text{k}\Omega$ & $6.8\,\text{k}\Omega$ & $1.2\,\text{k}\Omega$ & $6.8\,\text{nF}$ \\ \hline
			10 kHz -- 20 kHz  & $1.5\,\text{k}\Omega$ & $3.9\,\text{k}\Omega$ & $390\,\Omega$ & $6.8\,\text{nF}$ \\ \hline
		\end{tabular}
		\caption{Resistor and Capacitor values for 2nd \ac{MFB} Filter}
	\end{table}
	\section{\ac{PCB} Schematics}\label{app:PCB Schematics}
    \subsection*{\ac{PCB} Partitioning as a Cost-Reduction Strategy}

The initial hardware implementation consisted of two printed circuit boards (\ac{PCB}s): a main circuit \ac{PCB} measuring 162.94~mm~$\times$~112.52~mm and a display \ac{PCB} measuring 119.63~mm~$\times$~58.67~mm. The total estimated manufacturing cost for this configuration was approximately \$20. 

To minimize fabrication costs, the final design was divided into four smaller modular \ac{PCB}s, each with dimensions below 100~mm~$\times$~100~mm. This allowed the design to qualify for low-cost prototyping services offered by \ac{PCB} manufacturers. Consequently, the total fabrication cost was reduced to \$8 (four boards at \$2 each). This partitioning approach resulted in a \textbf{60\% reduction in manufacturing cost}, achieved without compromising system functionality or performance.

    \begin{figure}[H]
        \centering
        
        \caption{Pre-Amplifer \& Filters }
        \label{fig:placeholder}
    \end{figure}
      \begin{figure}[H]
        \centering
        
        \caption{Power Amplifier \& Display}
        \label{fig:placeholder1}
    \end{figure}
	
\end{document}

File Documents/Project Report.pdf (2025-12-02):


Department of Electronic & Telecommunication Engineering, University of Moratuwa, Sri Lanka.

# Five Band Audio Equalizer

Group Members:
230629R | Tennakoon U.G.R.B
230548R | Ratnayake R.M.S.H
230613M | Shehan M.N.N
230164K | Dissanayake R.K.T

Submitted in partial fulfillment of the requirements for the module EN 2091 Laboratory Practice and Projects

Date: December 2, 2025

Five Band Audio Equalizer | Electro Dieus

Abstract
The Five Band Audio Equalizer is an analog signal processing system designed to modify and enhance audio quality by adjusting the amplitude of distinct frequency bands within an audio signal. The system divides the input audio into five specific frequency ranges—20–300 Hz, 300 Hz–1 kHz, 1–4 kHz, 4–10 kHz, and 10–20 kHz—using precision-designed band-pass filters. Each band can be individually amplified or attenuated through a variable gain control stage, enabling users to shape the tonal balance according to preference or acoustic environment. A preamplifier circuit prepares the signal for processing, while a summing amplifier recombines the adjusted frequency bands to produce a clear and balanced output. Additionally, an Light Emitting Diode (LED)-based level display visually indicates the intensity of each band. The system is implemented using operational amplifiers (NE5532) and the LM3915 display driver, ensuring low noise, high fidelity, and efficient visualization. This project demonstrates practical applications of analog circuit design principles, including filter design, signal amplification, Printed Circuit Board (PCB) layout, and system integration for real-world audio enhancement.

## Abbreviations and Acronyms

PCB Printed Circuit Board

Op Amp Operational Amplifier

LED Light Emitting Diode

MFB Multiple Feedback

1

## Contents

1 Introduction and Functionality | 3
2 System Architecture | 3
3 Component Selection (Main electronic components) | 7
4 PCB Design | 8
5 Enclosure Design | 9
6 Software Simulation and Hardware Testing | 10
7 Conclusion & Future Works | 11
8 Contribution of Group Members | 12
A Practical Resistor & Capacitor Values | 13
B PCB Schematics | 13

2

## 1 Introduction and Functionality

An audio equalizer is a fundamental device used in sound systems to balance and adjust the amplitude of specific frequency components within an audio signal. It enables selective amplification or attenuation of chosen frequency ranges, thereby enhancing tonal quality and the overall listening experience.
In this project, a Five Band Audio Equalizer was developed using analog electronic circuits to divide the incoming audio signal into five distinct frequency bands:
- 20–300 Hz (Bass range)
- 300 Hz–1 kHz (Lower midrange)
- 1–4 kHz (Upper midrange)
- 4–10 kHz (Presence range)
- 10–20 kHz (Treble range)

20-300 Hz frequency band is processed using an unity gain Sallen-Key band-pass filter and other frequency bands processed through Multiple Feedback (MFB) filter to isolate its respective range. The filtered signals then pass through individual gain control stages, allowing users to adjust amplification levels via variable resistors. The processed signals are subsequently recombined using a summing amplifier to produce a customized and balanced output signal.
A pre-amplifier boosts the input audio signal to the required level, while a power amplifier (based on the LM386 IC) drives the final output with sufficient power. Furthermore, a LED level indicator circuit, implemented using the LM3915 LED display driver, provides real-time visual feedback of the audio levels across frequency bands.
Overall, this system integrates the concepts of analog filtering, amplification, and signal visualization into a single compact hardware unit, demonstrating the principles of audio signal processing and analog circuit design in a practical and educational context.

## 2 System Architecture

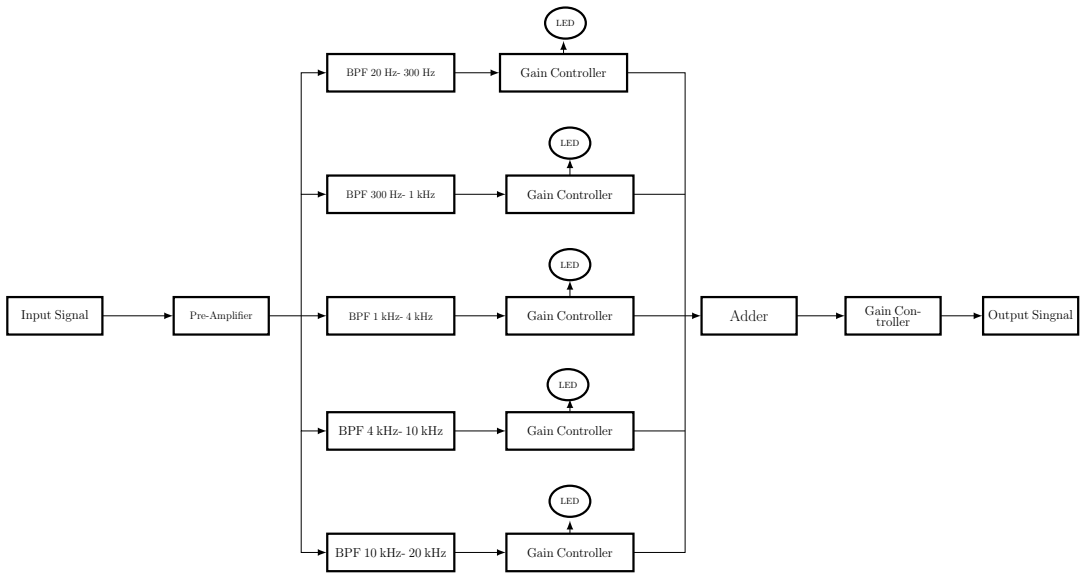
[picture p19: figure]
Input Signal; Pre-Amplifier; BPF 20 Hz- 300 Hz; BPF 1 kHz- 4 kHz; BPF 300 Hz- 1 kHz; BPF 4 kHz- 10 kHz; BPF 10 kHz- 20 kHz; Gain Controller; Adder; Gain Con-; troller; Output Singnal; LED

Figure 1: Functional Block Diagram

3

### 2.1 Pre-Amplifier Circuit

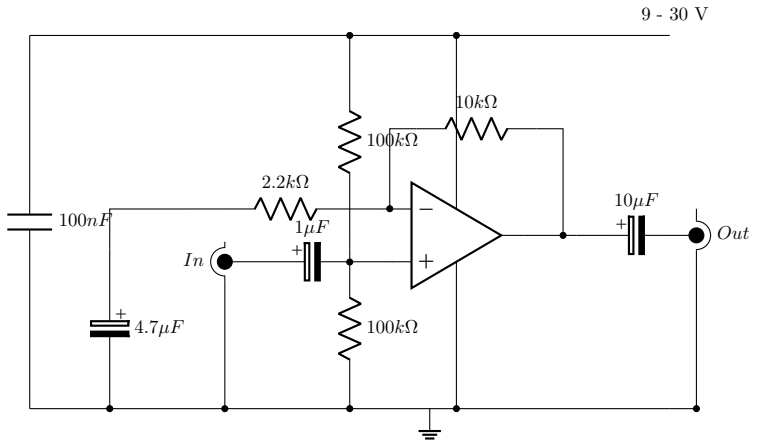
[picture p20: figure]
Out

Figure 2: Pre-Amplifier Circuit

### 2.2 Band Pass Filter Design

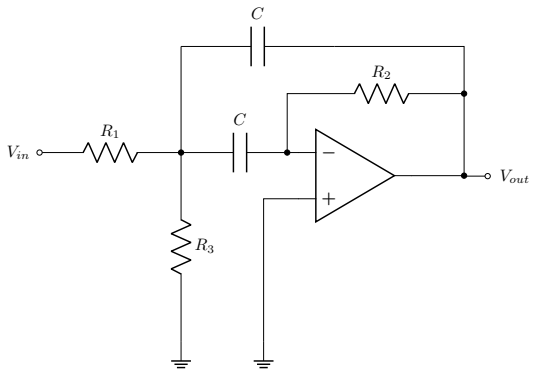
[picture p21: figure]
Vin; Vout

Figure 3: MFB Band-Pass filter

- Mid-frequency: fm =
1

2πC q R1+R3
R1R2R3
- Gain at fm: −Am =
R2
2R1
- Filter quality: Q = πfmR2C
- Bandwidth: B =
1
πR2C

The MFB band-pass allows to adjust Q, Am, and fm independently. Bandwidth and gain factor do not depend on R3. Therefore, R3 can be used to modify the mid frequency without affecting bandwidth, B, or gain, Am. Furthermore,

R1 =

R2
−2Am

, R2 =

Q
πfmC

, R3 =

−AmR1
2Q²+Am
In order to make Fourth-Order Band-Pass filter, we cascaded two MFB Band-Pass filters. The mid frequency of filter 1 is:

fm1 =

fm
α
the mid frequency of filter 2 is:
fm2 = fm · α

with Q being the quality factor of the overall filter.
The individual gain (Ami) at the partial mid frequencies, fm1 and fm2, is the same for both filters:

Ami =

Qi
Q

r
Am
B1

4

Unity-Gain Sallen-Key Band-Pass Filter (For 20-300 Hz)

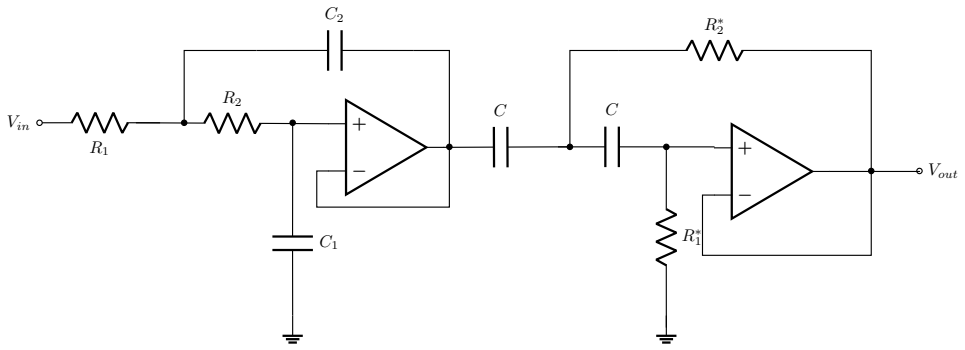
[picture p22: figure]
Vin; Vout

Figure 4: Unity-Gain Sallen-Key Band-Pass Filter

For given C1 and C2, the resistor values for R1 and R2 are calculated through:

R1,2 =

a1C2 ∓

p
a

2

1C²
2 − 4b1C1C2
4πfcC1C2

For given C, the resistor values for R∗ 1 and R∗
2 are calculated through:

R

∗
1 =

1
πfcCa1

, R∗
2 =

a1
4πfcCb1

Calculated Theoretical Resistor & Capacitor Values for Band-pass Filters¹

R1 | R2 | C1 | C2 | R∗ 1 | R∗ 2 | C
1.2 kΩ | 2.2 kΩ | 220 nF | 470 nF | 47 kΩ | 27 kΩ | 220 nF

Table 1: Resistor and Capacitor values (20 Hz – 300 Hz)

Frequency Range | R1 | R2 | R3 | C
300 Hz – 1 kHz 1 kHz – 4 kHz 4 kHz – 10 kHz 10 kHz – 20 kHz | 3.3 kΩ 2.7 kΩ 2.2 kΩ 2.2 kΩ | 10 kΩ 8.2 kΩ 6.8 kΩ 5.6 kΩ | 3.9 kΩ 6.8 kΩ 1 kΩ 390 Ω | 100 nF 33 nF 15 nF 10 nF

Table 2: Resistor and Capacitor values for 1st MFB Filter

Frequency Range | R1 | R2 | R3 | C
300 Hz – 1 kHz 1 kHz – 4 kHz 4 kHz – 10 kHz 10 kHz – 20 kHz | 15 kΩ 3.3 kΩ 2.7 kΩ 1.8 kΩ | 47 kΩ 10 kΩ 8.2 kΩ 5.6 kΩ | 15 kΩ 6.8 kΩ 1 kΩ 330 Ω | 10 nF 10 nF 6.8 nF 6.8 nF

Table 3: Resistor and Capacitor values for 2nd MFB Filter

1See Appendix A for practical resistor & capacitor values.

5

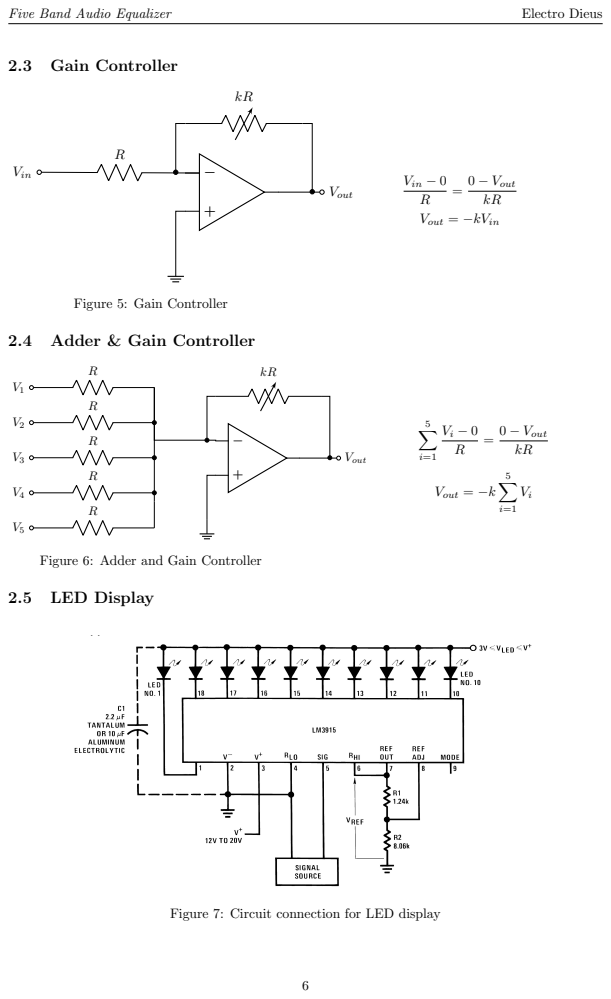
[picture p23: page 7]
2.3 Gain Controller; Vin; Vout; Vin − 0; 0 − Vout; Vout = −kVin; Vout = −k; 2.5 LED Display

Figure 5: Gain Controller

2.4 Adder & Gain Controller

Figure 6: Adder and Gain Controller

Figure 7: Circuit connection for LED display

### 2.6 Power Amplifier Circuit

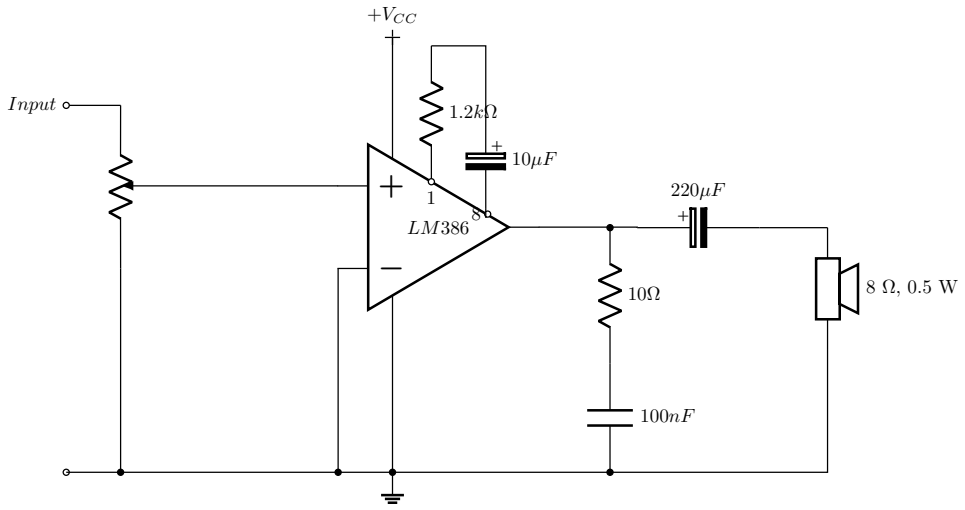
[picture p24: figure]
Input; +VCC

Figure 8: Power Amplifier Circuit

## 3 Component Selection (Main electronic components)

1. NE5532 Operational Amplifier
- Low Noise: 5 nV/√
Hz suitable for high-fidelity audio
- Bipolar Input: Ensures low offset and distortion in precision audio
- Dual Channel: Two Operational Amplifier (Op Amp) per IC for compact design
- High Slew Rate: 9 V/µs supports wide dynamic range
- Wide Bandwidth: 10 MHz gain-bandwidth product for audio applications
- Wide Supply: ±3 V to ±20 V operation for design flexibility
- High Drive Capability: Can directly drive 600 Ω loads
2. LM3915 Dot/Bar Display Driver
- Logarithmic 3 dB/step response for audio
- Direct LED drive without current-limiting resistors
- Simple setup with minimal external components
- Over-voltage protection (±35V) on input


Figure 9: NE5532P Operational Amplifier Figure 10: LM3915 Dot/Bar Display Driver

7

## 4 PCB Design

We designed 4 separate PCBs using Altium Designer. (Why 4 PCBs?² )


Figure 11: 2D pathway of Pre Amplifier Circuit


Figure 12: 2D pathway of Filter Circuit


Figure 13: 2D pathway of Power Amplifier Circuit


Figure 14: 2D pathway of LED Display Circuit


Figure 15: Soldered PCBs

2See Appendix B.

8

## 5 Enclosure Design


Figure 16: Enclosure front view


Figure 17: Right side view


Figure 18: Back view


Figure 19: Left side view


Figure 20: Final product

9

## 6 Software Simulation and Hardware Testing


### 6.1 Software Simulation (Using LTspice)

Figure 21: Circuit Diagram

Figure 22: Frequency Response of Each Filter

10


Figure 23: Overall Frequency Response

### 6.2 Hardware Testing


Figure 24: Breadboard implementation | Figure 25: PCB testing

## 7 Conclusion & Future Works

The Five Band Audio Equalizer successfully achieves its primary objective of dividing an input audio signal into five distinct frequency bands and allowing individual gain control for each band. Through the integration of pre-amplifier, band-pass filter, gain control, adder, and power amplifier stages, the system provides a fully analog audio equalization platform with real-time visual feedback using an LED display. The implemented filters effectively cover the entire audible range from 20 Hz to 20 kHz, enabling fine-tuned tonal adjustment and improved sound clarity. Experimental testing confirmed that the circuit delivers stable operation with low distortion and noise, demonstrating the effectiveness of the NE5532 Op Amp and LM3915 LED display driver in high-fidelity analog applications.
Future development of the project can focus on several enhancements. Firstly, the system can be expanded into a stereo equalizer by duplicating the current design for left and right audio channels, enabling complete two-channel sound processing for improved spatial audio experience. Secondly, designing a dedicated power supply unit with voltage regulation and filtering will ensure stable performance and minimize noise interference. Additional improvements could include integrating tone presets, miniaturized PCB layouts, and incorporating protection circuits to increase durability and user convenience. These developments would transform the prototype into a fully functional and reliable consumer-grade audio equalizer system.

11

## 8 Contribution of Group Members

Student’s Name (Index No.) | Contribution
Tennakoon U.G.R.B. (230629R) | Filter calculations, PCB design, Testing & debugging, Sol-dering
Ratnayake R.M.S.H. (203548R) | PCB design, Circuits design, Circuits simulation, Soldering
Shehan M.N.N. (230613M) | Breadboard implementation, Enclosure Design, Testing
Dissanayake R.K.T. (230164K) | LED display circuit design & breadboard implementation, Testing, Assembling

## Acknowledgment

We would like to express our sincere gratitude to Mr. Chanula Luckshan, our project supervisor, for his continuous guidance and support throughout the development of the Five Band Audio Equalizer project. His valuable suggestions at the early stages of circuit design and his assistance in identifying and correcting errors during PCB and enclosure design were instrumental in achieving a successful outcome.
We also wish to extend our appreciation to Dr. Pranjeevan Kulasingham, our Signals and Systems lecturer, for providing us with a comprehensive understanding of analog filter design principles, which formed the foundation for our filter implementation in this project.
Our heartfelt thanks go to Dr. Sampath Perera, the module coordinator of EN2091 Laboratory Practice and Projects, for his overall supervision, encouragement, and for providing the necessary resources to complete this project effectively.
Finally, we would like to acknowledge the support of all the laboratory assistants of the Department of Electronic and Telecommunication Engineering for their technical help, timely guidance, and assistance during the hardware testing and implementation stages.

## References

[1] Texas | Instruments, | op | Amps | for | Everyone | Design | Guide, | Rev. | 8, | Ad-
vanced | Analog | Products, | SLOD006B, | Aug. | 2002. | [Online]. | Available:
https://web.mit.edu/6.101/www/reference/op amps everyone.pdf
[2] Texas Instruments, “NE5532 — Dual, 30-V, 10-MHz, low-noise operational amplifier for audio applications,” TI product page (Datasheet Rev. J), Jan. 27, 2015. [Online]. Available: https: //www.ti.com/product/NE5532
[3] Texas Instruments. LM3915 Dot/Bar Display Driver Datasheet, SNVS740C. Revised Mar. 2013. [Online]. Available: https://www.alldatasheet.com/datasheet-pdf/view/558236/TI/LM3915.html (https://www.alldatasheet.com/datasheet-pdf/view/558236/TI/LM3915.html)
[4] “Op Amp Preamplifier Circuits – For MICs, Guitars, Pick-ups, Buffers.” Homemade Cir-
cuits. Last Updated: | Sept. 13, 2023. Available: | https://www.homemade-circuits.com/
op-amp-preamplifier-circuits-for-mics-guitars-pick-ups-as-buffer/ (https://www.homemade-circuits.com/op-amp-preamplifier-circuits-for-mics-guitars-pick-ups-as-buffer/)
[5] A. Garaipoom, “LM386 Audio Amp Circuit – Build Small, Loud & Battery-Friendly!,” ElecCircuit.com. Last Updated: Sept. 17, 2025. Available: https://www.eleccircuit.com/lm386-audio-amplifier-circuit/ (https://www.eleccircuit.com/lm386-audio-amplifier-circuit/)

12

## Appendix

## A Practical Resistor & Capacitor Values

R1 | R2 | C1 | C2 | R∗ 1 | R∗ 2 | C
1.2 kΩ | 2.2 kΩ | 220 nF | 470 nF | 47 kΩ | 27 kΩ | 220 nF

Table 4: Resistor and Capacitor values (20 Hz – 300 Hz)

Frequency Range | R1 | R2 | R3 | C
300 Hz – 1 kHz | 2.7 kΩ | 10 kΩ | 10 kΩ | 100 nF
1 kHz – 4 kHz | 2.7 kΩ | 8.2 kΩ | 15 kΩ | 33 nF
4 kHz – 10 kHz | 2.2 kΩ | 6.8 kΩ | 1.2 kΩ | 15 nF
10 kHz – 20 kHz | 1.8 kΩ | 5.6 kΩ | 470 Ω | 10 nF

Table 5: Resistor and Capacitor values for 1st MFB Filter

Frequency Range | R1 | R2 | R3 | C
300 Hz – 1 kHz | 8.2 kΩ | 27 kΩ | 27 kΩ | 10 nF
1 kHz – 4 kHz | 2.2 kΩ | 8.2 kΩ | 15 kΩ | 10 nF
4 kHz – 10 kHz | 2.2 kΩ | 6.8 kΩ | 1.2 kΩ | 6.8 nF
10 kHz – 20 kHz | 1.5 kΩ | 3.9 kΩ | 390 Ω | 6.8 nF

Table 6: Resistor and Capacitor values for 2nd MFB Filter

## B PCB Schematics

PCB Partitioning as a Cost-Reduction Strategy

The initial hardware implementation consisted of two printed circuit boards (PCBs): a main circuit PCB measuring 162.94 mm × 112.52 mm and a display PCB measuring 119.63 mm × 58.67 mm. The total estimated manufacturing cost for this configuration was approximately $20.
To minimize fabrication costs, the final design was divided into four smaller modular PCBs, each with dimensions below 100 mm × 100 mm. This allowed the design to qualify for low-cost prototyping services offered by PCB manufacturers. Consequently, the total fabrication cost was reduced to $8 (four boards at $2 each). This partitioning approach resulted in a 60% reduction in manufacturing cost, achieved without compromising system functionality or performance.

13


Figure 26: Pre-Amplifer & Filters


Figure 27: Power Amplifier & Display

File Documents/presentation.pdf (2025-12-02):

Introduction | PCB Design | Enclosure Design | Conclusion

# Five Band Audio Equalizer

# Disssanayake R.K.T.(230164K) Ratnayake R.M.S.H.(230548R) Shehan M.N.N.(230613M) Tennakoon U.G.R.B.(230629R)

### Department of Electronic & Telecommunication Engineering University of Moratuwa, Sri Lanka

# December 11, 2025

Electro Dieus | EN2091 Laboratory Practice & Projects | December 11, 2025 | 1 / 18

# Presentation Structure

# 1 Introduction

# 2 PCB Design

# 3 Enclosure Design

# 4 Conclusion

Electro Dieus | EN2091 Laboratory Practice & Projects | December 11, 2025 | 2 / 18

# Introduction

Electro Dieus | EN2091 Laboratory Practice & Projects | December 11, 2025 | 3 / 18

# System Architecture

Input Signal; Pre-Amplifier; BPF 20 Hz- 300 Hz; BPF 1 kHz- 4 kHz; BPF 300 Hz- 1 kHz; BPF 4 kHz- 10 kHz; BPF 10 kHz- 20 kHz; Gain Controller; Adder; Output Singnal; LED

Electro Dieus | EN2091 Laboratory Practice & Projects | December 11, 2025 | 4 / 18

# Component Selection Justification

# 1 NE5532 Operational Amplifier

- Low Noise: 5 nV/√ Hz suitable for high-fidelity audio - Bipolar Input: Ensures low offset and distortion in precision audio - Dual Channel: Two op-amps per IC for compact design - High Slew Rate: 9 V/µs supports wide dynamic range - Wide Bandwidth: 10 MHz gain-bandwidth product for audio applications - Wide Supply: ±3 V to ±20 V operation for design flexibility - High Drive Capability: Can directly drive 600 Ω loads

# 2 LM3915 Dot/Bar Display Driver

## - Logarithmic 3 dB/step response for audio - Direct LED drive without current-limiting resistors - Simple setup with minimal external components - Over-voltage protection (±35V) on input

Electro Dieus | EN2091 Laboratory Practice & Projects | December 11, 2025 | 5 / 18

# Component Selection Justification (Contd..)


Figure: NE5532 Operational Amplifier | Figure: LM3915 Dot/Bar Display Driver
Electro Dieus | EN2091 Laboratory Practice & Projects | December 11, 2025 | 6 / 18

# PCB Design

Electro Dieus | EN2091 Laboratory Practice & Projects | December 11, 2025 | 7 / 18

# PCB 2D Pathways


Figure: Pre-Amplifier Circuit | Figure: Power Amplifier
Electro Dieus | EN2091 Laboratory Practice & Projects | December 11, 2025 | 8 / 18

# PCB 2D Pathways (Contd...)


Figure: Filters | Figure: LED Display
Electro Dieus | EN2091 Laboratory Practice & Projects | December 11, 2025 | 9 / 18

# PCB Partitioning: A Cost-Effective Approach

# Initial Design: 2 PCBs

# - Main Circuit PCB: 162.94 mm × 112.52 mm

# - Display PCB: 119.63 mm × 58.67 mm

# - Total Estimated Cost: ≈$20

# Final Design: 4 PCBs

# - Four smaller, modular boards, each under 100 mm × 100 mm

# - Standard size qualifying for low-cost prototyping services

# - Total Cost: 4 boards × $2 = $8

# Key Outcome: 60% Cost Reduction

# By splitting the design into four smaller, standardized panels, we achieved a significant 60% reduction in manufacturing cost without

compromising system functionality or performance.

Electro Dieus | EN2091 Laboratory Practice & Projects | December 11, 2025 | 10 / 18

# PCB Testing


# Click to Play Video

Electro Dieus | EN2091 Laboratory Practice & Projects | December 11, 2025 | 11 / 18

# Enclosure Design

Electro Dieus | EN2091 Laboratory Practice & Projects | December 11, 2025 | 12 / 18

# Enclosure Design


# Click to Play Video

Electro Dieus | EN2091 Laboratory Practice & Projects | December 11, 2025 | 13 / 18

# Final Product


## Figure: Five Band Audio Equalizer

Electro Dieus | EN2091 Laboratory Practice & Projects | December 11, 2025 | 14 / 18

# Conclusion

Electro Dieus | EN2091 Laboratory Practice & Projects | December 11, 2025 | 15 / 18

# Technical Challenges & Solutions

# Op-Amp Signal Distortion

# - Problem: TL072 op-amps caused severe distortion at high

# frequencies - Solution: Upgraded to NE5532 for better slew rate and bandwidth

# - Result: Clean signal across all frequency bands

# Filter Component Mismatch

# - Problem: Theoretical resistor values didn’t match practical

# performance - Solution: Recalculated values and verified -3 dB points with

# oscilloscope - Result: Precisely tuned filters meeting all specifications

Electro Dieus | EN2091 Laboratory Practice & Projects | December 11, 2025 | 16 / 18

# Contribution of Group Members

Student’s Name (Index No.) | Contribution
Tennakoon U.G.R.B. (230629R) | Filter calculations, PCB design, Test-ing & debugging, Soldering
Ratnayake R.M.S.H. (203548R) | PCB design, Circuits design, Circuits simulation, Soldering
Shehan M.N.N. (230613M) | Breadboard implementation, Enclo-sure Design, Testing
Dissanayake R.K.T. (230164K) | LED display circuit design & bread-board implementation, Testing, As-sembling
Electro Dieus | EN2091 Laboratory Practice & Projects | December 11, 2025 | 17 / 18

# Thank You!

Electro Dieus | EN2091 Laboratory Practice & Projects | December 11, 2025 | 18 / 18


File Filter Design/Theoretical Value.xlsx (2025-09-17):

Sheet: Sheet1
Lower (Hz) | Upper(Hz) | Mid | Bandwith | R1 | R3 | R2 | C1 | Mid | BW | Am | Q | R4 | R6 | R5 | C2 | Mid | BW | Am | Q
20 | 300 | 77.45966692 | 280 | 10000 | 82000 | 39000 | 1e-07 | 85.4 | 81.62 | -1.95 | 1.05 | 2700 | 22000 | 10000 | 1e-07 | 324.5 | 318.31 | -1.85 | 1.02
300 | 1000.00 | 547.7225575 | 700 | 3600 | 3900 | 11000 | 1e-07 | 350.7 | 289.37 | -1.53 | 1.21 | 15000 | 15000 | 47000 | 1e-08 | 847.7 | 677.26 | -1.57 | 1.25
1000.00 | 4000.00 | 2000 | 3000 | 2700 | 6200 | 9100 | 3.3e-08 | 1165.7 | 1059.97 | -1.69 | 1.10 | 3000 | 6500 | 10000 | 1e-08 | 3512.9 | 3183.10 | -1.67 | 1.10
4000.00 | 10000.00 | 6324.55532 | 6000 | 2400 | 1000 | 7500 | 1.5e-08 | 4611.4 | 2829.42 | -1.56 | 1.63 | 2700 | 1000 | 8200 | 6.8e-09 | 9568.0 | 5708.57 | -1.52 | 1.68
10000.00 | 20000.00 | 14142.13562 | 10000 | 2200 | 390 | 5600 | 1e-08 | 11685.1 | 5684.11 | -1.27 | 2.06 | 1800 | 330 | 5600 | 6.8e-09 | 18729.0 | 8358.98 | -1.56 | 2.24
 |  |  | USE ABOVE TABLES TO RECALCULATE IF THE CHOSEN VALUES ARE CORRECT
GAIN OF 4TH ORDER FILTER TO CALCULATE THE0RETICAL VALUES
1
1 |  |  | fm
1 |  |  | 166.4466661
1 |  |  | 545.2626111
1 |  |  | 2023.642074
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

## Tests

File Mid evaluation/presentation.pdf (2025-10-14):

Introduction | Filter Design | Other Circuits | PCB Design | Conclusion

# Five Band Audio Equalizer

# Disssanayake R.K.T.(230164K) Ratnayake R.M.S.H.(230548R) Shehan M.N.N.(230613M) Tennakoon U.G.R.B.(230629R)

### Department of Electronic & Telecommunication Engineering University of Moratuwa, Sri Lanka

# October 14, 2025

Electro Dieus | EN2091 Laboratory Practice & Projects | October 14, 2025 | 1 / 23

# Presentation Structure

# 1 Introduction

# 2 Filter Design

# 3 Other Circuits

# 4 PCB Design

Electro Dieus | EN2091 Laboratory Practice & Projects | October 14, 2025 | 2 / 23

# Component Selection Justification

# 1 NE5532 Operational Amplifier

- Low Noise: 5 nV/√ Hz suitable for high-fidelity audio - Bipolar Input: Ensures low offset and distortion in precision audio - Dual Channel: Two op-amps per IC for compact design - High Slew Rate: 9 V/µs supports wide dynamic range - Wide Bandwidth: 10 MHz gain-bandwidth product for audio applications - Wide Supply: ±3 V to ±20 V operation for design flexibility - High Drive Capability: Can directly drive 600 Ω loads

# 2 LM3915 Dot/Bar Display Driver

## - Logarithmic 3 dB/step response for audio - Direct LED drive without current-limiting resistors - Simple setup with minimal external components - Over-voltage protection (±35V) on input

Electro Dieus | EN2091 Laboratory Practice & Projects | October 14, 2025 | 3 / 23

# Component Selection Justification (Cont.)

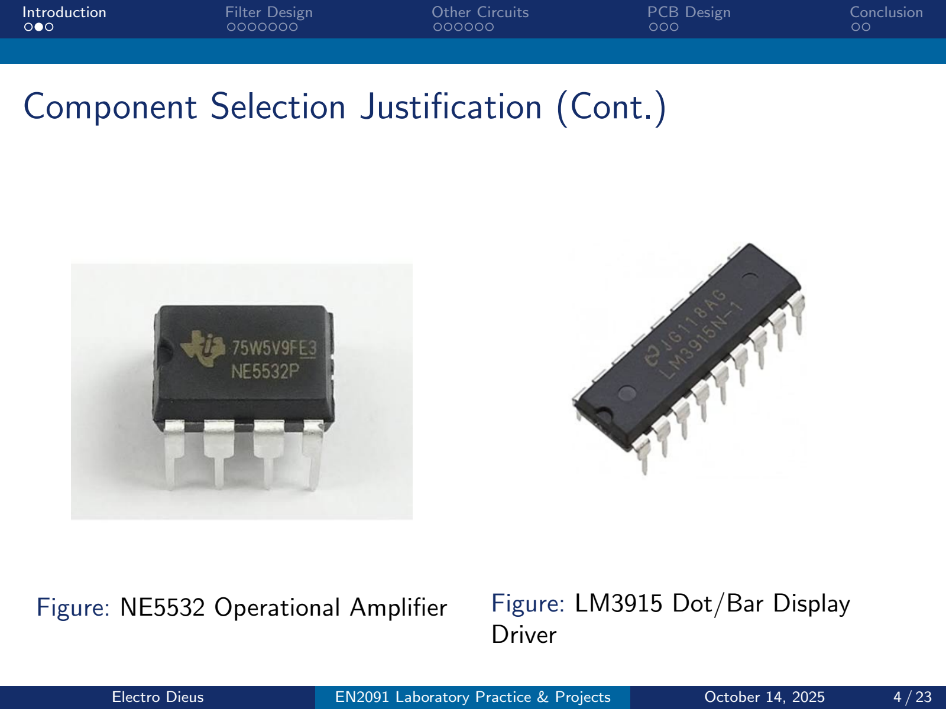
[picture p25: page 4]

Figure: NE5532 Operational Amplifier | Figure: LM3915 Dot/Bar Display Driver
Electro Dieus | EN2091 Laboratory Practice & Projects | October 14, 2025 | 4 / 23

# System Architecture

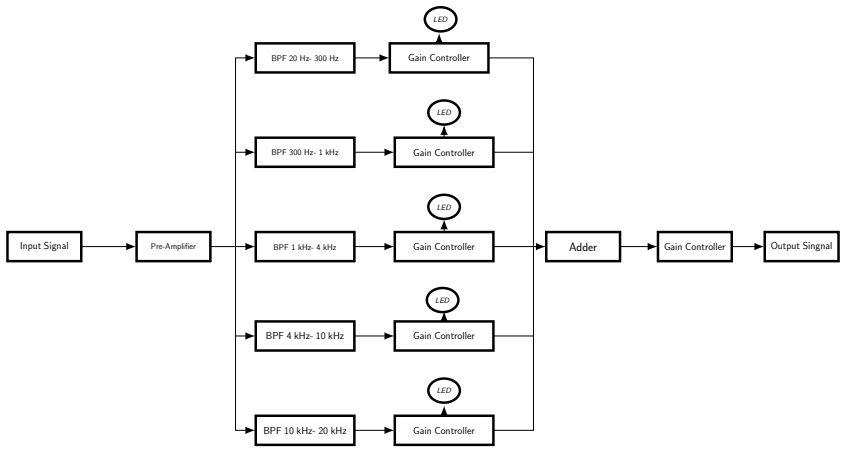
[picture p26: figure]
Input Signal; Pre-Amplifier; BPF 20 Hz- 300 Hz; BPF 1 kHz- 4 kHz; BPF 300 Hz- 1 kHz; BPF 4 kHz- 10 kHz; BPF 10 kHz- 20 kHz; Gain Controller; Adder; Output Singnal; LED

Electro Dieus | EN2091 Laboratory Practice & Projects | October 14, 2025 | 5 / 23

# Filter Design

Electro Dieus | EN2091 Laboratory Practice & Projects | October 14, 2025 | 6 / 23

# MFB Band-Pass Filter

C

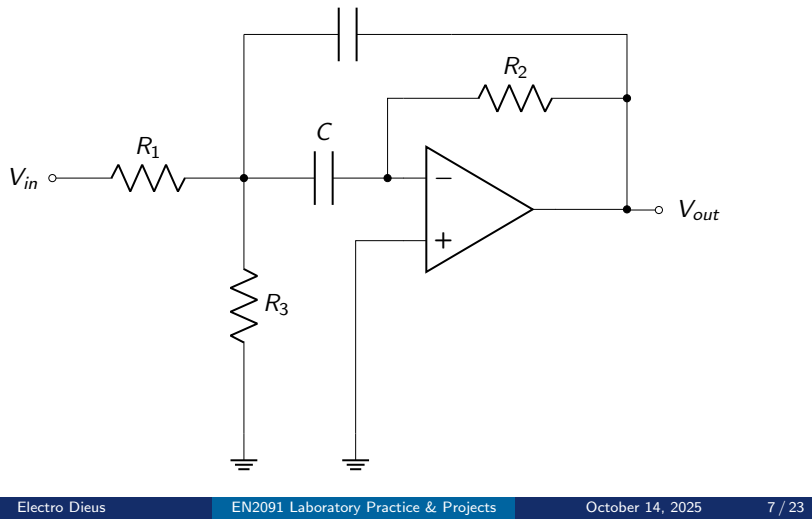
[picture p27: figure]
Vin; Vout; Electro Dieus; EN2091 Laboratory Practice & Projects; October 14, 2025

# MFB Band-Pass Filter (Cont.)

# - mid-frequency: fm =

1
2πC

### q R1+R3 R1R2R3

# - gain at fm: −Am =

R2
2R1

# - filter quality: Q = πfmR2C

# - bandwidth: B =

1

### πR2C

The MFB band-pass allows to adjust Q, Am, and fm independently.

# Bandwidth and gain factor do not depend on R3. Therefore, R3 can be

used to modify the mid frequency without affecting bandwidth, B, or gain, Am. Furthermore,

R1 =

R2
−2Am

, R2 =

Q

### πfmC

, R3 =

### −AmR1 2Q²+Am

Electro Dieus | EN2091 Laboratory Practice & Projects | October 14, 2025 | 8 / 23

# Fourth-Order Band-Pass Filter (Staggered Tuning)

# In order to make Fourth-Order Band-Pass filter, we cascaded two MFB

Band-Pass filters.

# The mid frequency of filter 1 is:

fm1 =

fm
α

# the mid frequency of filter 2 is:

### fm2 = fm · α

with Q being the quality factor of the overall filter.

# The individual gain (Ami) at the partial mid frequencies, fm1 and fm2, is the same for both filters:

# Ami =

Qi
Q

r
Am
B1
Electro Dieus | EN2091 Laboratory Practice & Projects | October 14, 2025 | 9 / 23

# Unity-Gain Sallen-Key Band-Pass Filter (For 20-300 Hz)

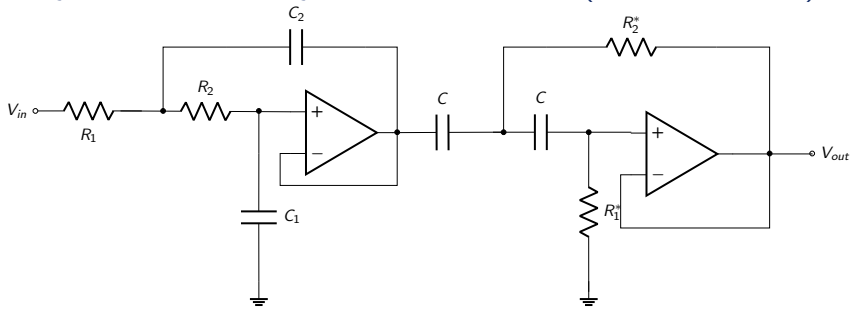
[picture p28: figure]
Vin; Vout

## For given C1 and C2, the resistor values for R1 and R2 are calculated through:

R1,2 =

a1C2 ∓

p
a

2
1C

2
2 − 4b1C1C2

## 4πfcC1C2 For given C, the resistor values for R

∗
1

## and R

∗
2

## are calculated through:

R

∗
1 =

1

## πfcCa1

, R

∗
2 =

a1

## 4πfcCb1

Electro Dieus | EN2091 Laboratory Practice & Projects | October 14, 2025 | 10 / 23

# Resistor & Capacitor Values

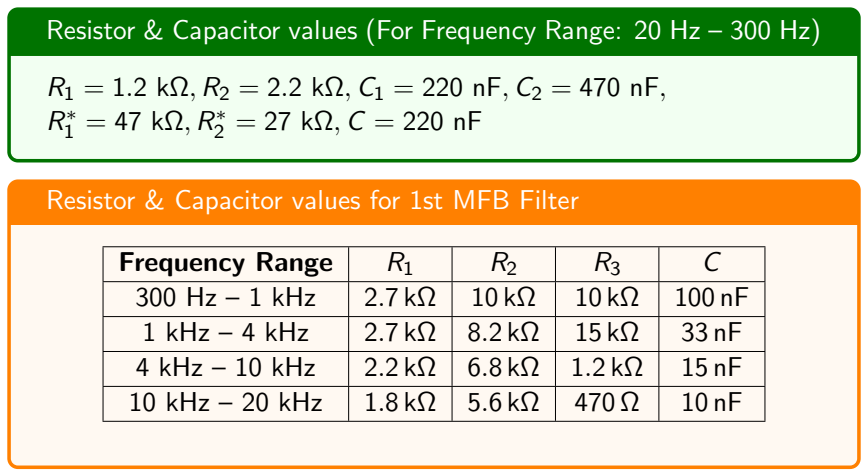
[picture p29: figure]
Frequency Range; 1 kHz – 4 kHz

# Resistor & Capacitor values (For Frequency Range: 20 Hz – 300 Hz)

R1 = 1.2 kΩ, R2 = 2.2 kΩ, C1 = 220 nF, C2 = 470 nF,

# Resistor & Capacitor values for 1st MFB Filter

300 Hz – 1 kHz | 2.7 kΩ | 10 kΩ | 10 kΩ | 100 nF
4 kHz – 10 kHz | 2.2 kΩ | 6.8 kΩ | 1.2 kΩ | 15 nF
10 kHz – 20 kHz | 1.8 kΩ | 5.6 kΩ | 470 Ω | 10 nF
Electro Dieus | EN2091 Laboratory Practice & Projects | October 14, 2025 | 11 / 23

# Resistor & Capacitor Values (Cont.)

# Resistor & Capacitor values for 2nd MFB Filter

Frequency Range | R1 | R2 | R3 | C
300 Hz – 1 kHz | 8.2 kΩ | 27 kΩ | 27 kΩ | 10 nF
1 kHz – 4 kHz | 2.2 kΩ | 8.2 kΩ | 15 kΩ | 10 nF
4 kHz – 10 kHz | 2.2 kΩ | 6.8 kΩ | 1.2 kΩ | 6.8 nF
10 kHz – 20 kHz | 1.5 kΩ | 3.9 kΩ | 390 Ω | 6.8 nF
Electro Dieus | EN2091 Laboratory Practice & Projects | October 14, 2025 | 12 / 23

# Other Circuits

Electro Dieus | EN2091 Laboratory Practice & Projects | October 14, 2025 | 13 / 23

# Gain Controller

kR

### Vin

### Vout

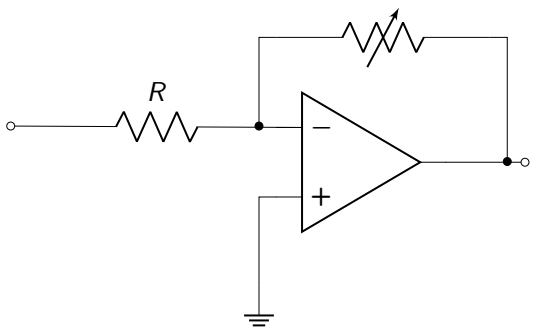
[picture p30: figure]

# Vin − 0

R

=

### 0 − Vout

kR

### Vout = −kVin

Electro Dieus | EN2091 Laboratory Practice & Projects | October 14, 2025 | 14 / 23

# Adder & Volume Controller

kR

R
V1

V2

V3

V4

V5

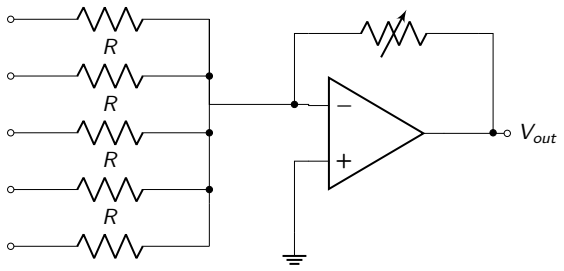
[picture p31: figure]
Vout

X

5

i=1

Vi − 0
R

=

### 0 − Vout

kR

Hence,

# Vout = −k

X

5

i=1

Vi

Electro Dieus | EN2091 Laboratory Practice & Projects | October 14, 2025 | 15 / 23

# LED Display

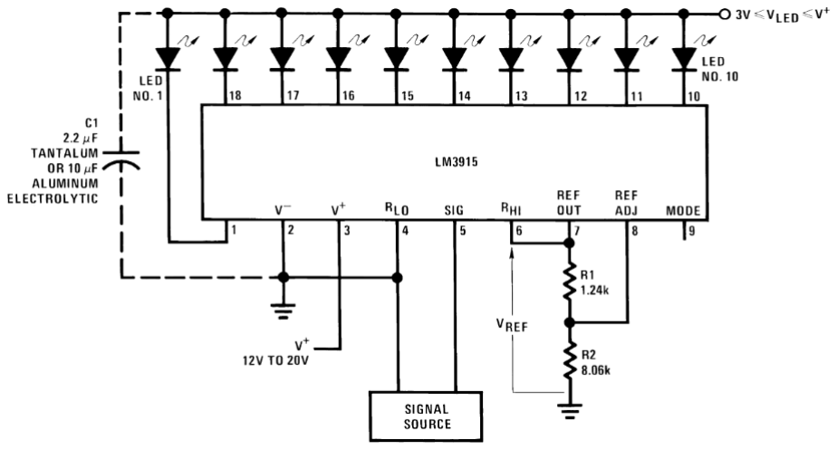
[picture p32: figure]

## Figure: Circuit connection for LED display[2]

Electro Dieus | EN2091 Laboratory Practice & Projects | October 14, 2025 | 16 / 23

# Pre-Amplifier Circuit¹

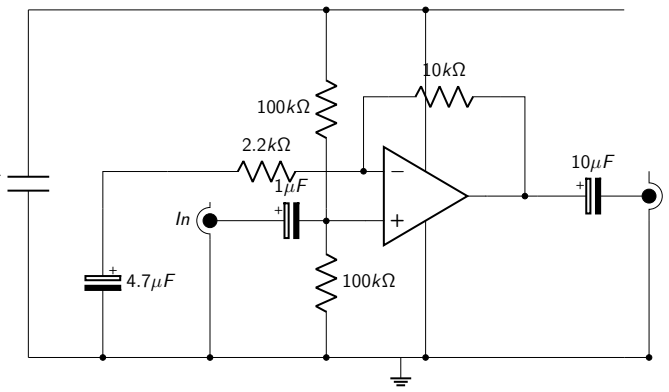
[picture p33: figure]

100nF

### Out

9 - 30 V

1

## https://www.homemade-circuits.com

Electro Dieus | EN2091 Laboratory Practice & Projects | October 14, 2025 | 17 / 23

# Power Amplifier Circuit²

2

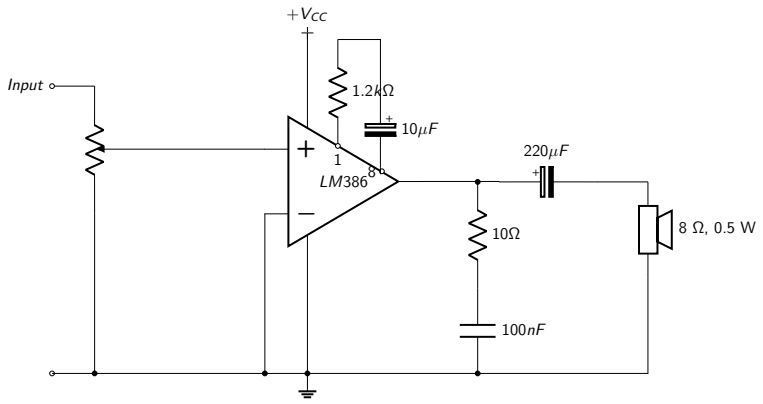
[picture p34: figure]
Input; +VCC

## https://www.eleccircuit.com/lm386-audio-amplifier-circuit/

Electro Dieus | EN2091 Laboratory Practice & Projects | October 14, 2025 | 18 / 23

# PCB Design

Electro Dieus | EN2091 Laboratory Practice & Projects | October 14, 2025 | 19 / 23

# PCB for Main Circuit


REV. SHT. DWG. NO.

DATE | PROJECT * | * * APPROVALS * *
ENG: * DSN: Senuda Ratnayake CHK: Ravindu Tennakoon BOM: REFERENCE DOCUMENTS | --/--/----/--/----/--/-- | PROJECT REVISION: Not in version control DOCUMENT REVISION: Not in version control DESIGN ITEM: TITLE *

# PCB for LED Display Circuit


THIS DOCUMENT AND THE DATA DISCLOSED HEREIN OR HEREWITH IS THE PROPERTY OF ALTIUM LIMITED AND MAY BE FREELY DISTRIBUTED IN WHOLE. NO RIGHTS ARE RESERVED OR EXPRESS OR IMPLIED WARANTEE GIVEN. | REVISION DESCRIPTION DATE APPROVED R1 GND

DATE | PROJECT | * * APPROVALS * *
ENG: * DSN: Senuda Ratnayake CHK: * REFERENCE DOCUMENTS | PROJECT REVISION: Not in version control DOCUMENT REVISION: Not in version control DESIGN ITEM: TITLE *

BOM: ASSY DWG: | SIZE CAGE CODE DWG NO. REV A3 Sheet2.SchDoc 1

FAB DWG: PCB DWG: | SCALE: | FILE NAME | SHEET | OF 1

# References

Texas Instruments, Top Amps for Everyone Design Guide, Rev. 8, Advanced Analog Products, SLOD006B, Aug. 2002. [Online].

# Available: https:

## //web.mit.edu/6.101/www/reference/op_amps_everyone.pdf

Texas Instruments. LM3915 Dot/Bar Display Driver Datasheet,

# SNVS740C. Revised Mar. 2013. [Online]. Available:

## https://www.alldatasheet.com/datasheet-pdf/view/558236/ TI/LM3915.html (https://www.alldatasheet.com/datasheet-pdf/view/558236/TI/LM3915.html)

Electro Dieus | EN2091 Laboratory Practice & Projects | October 14, 2025 | 22 / 23

# Thank You!

Electro Dieus | EN2091 Laboratory Practice & Projects | October 14, 2025 | 23 / 23

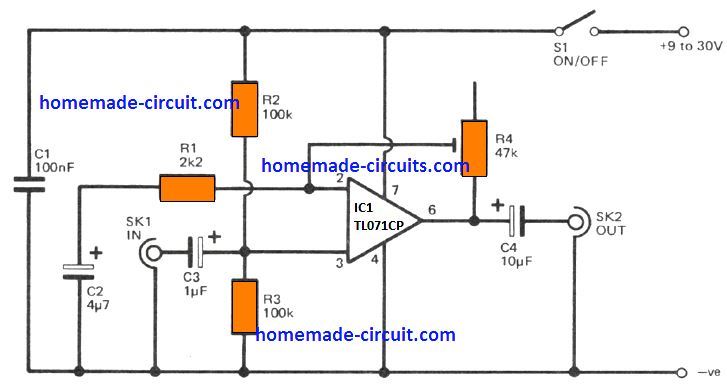
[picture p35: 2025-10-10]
Mid evaluation/amp.jpg

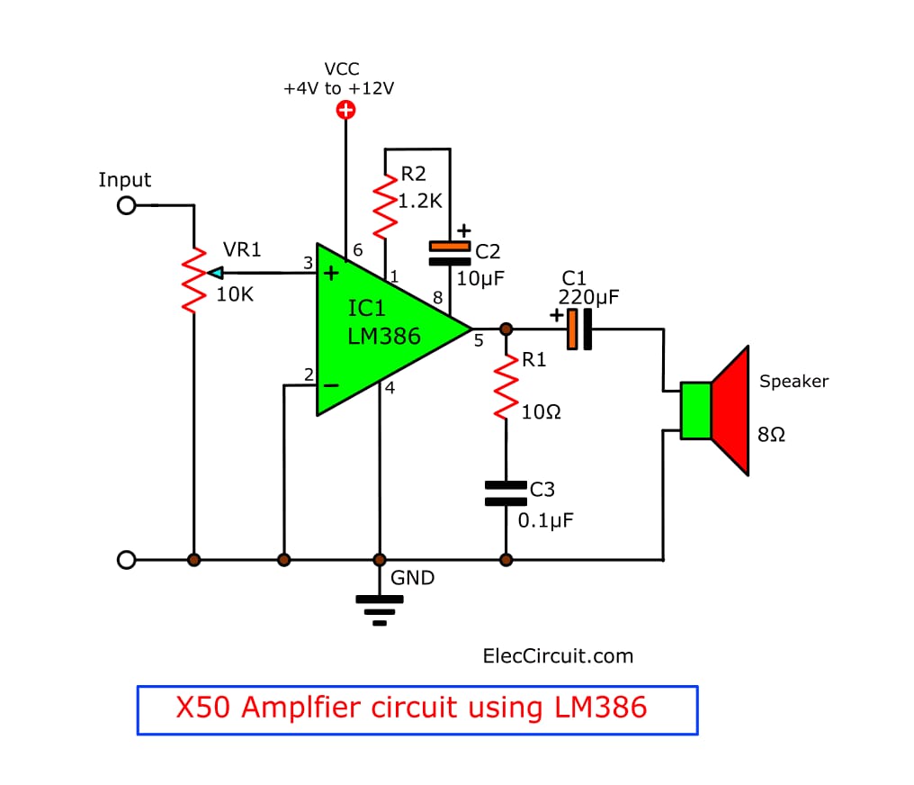
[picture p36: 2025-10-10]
Mid evaluation/pow amp.jpg

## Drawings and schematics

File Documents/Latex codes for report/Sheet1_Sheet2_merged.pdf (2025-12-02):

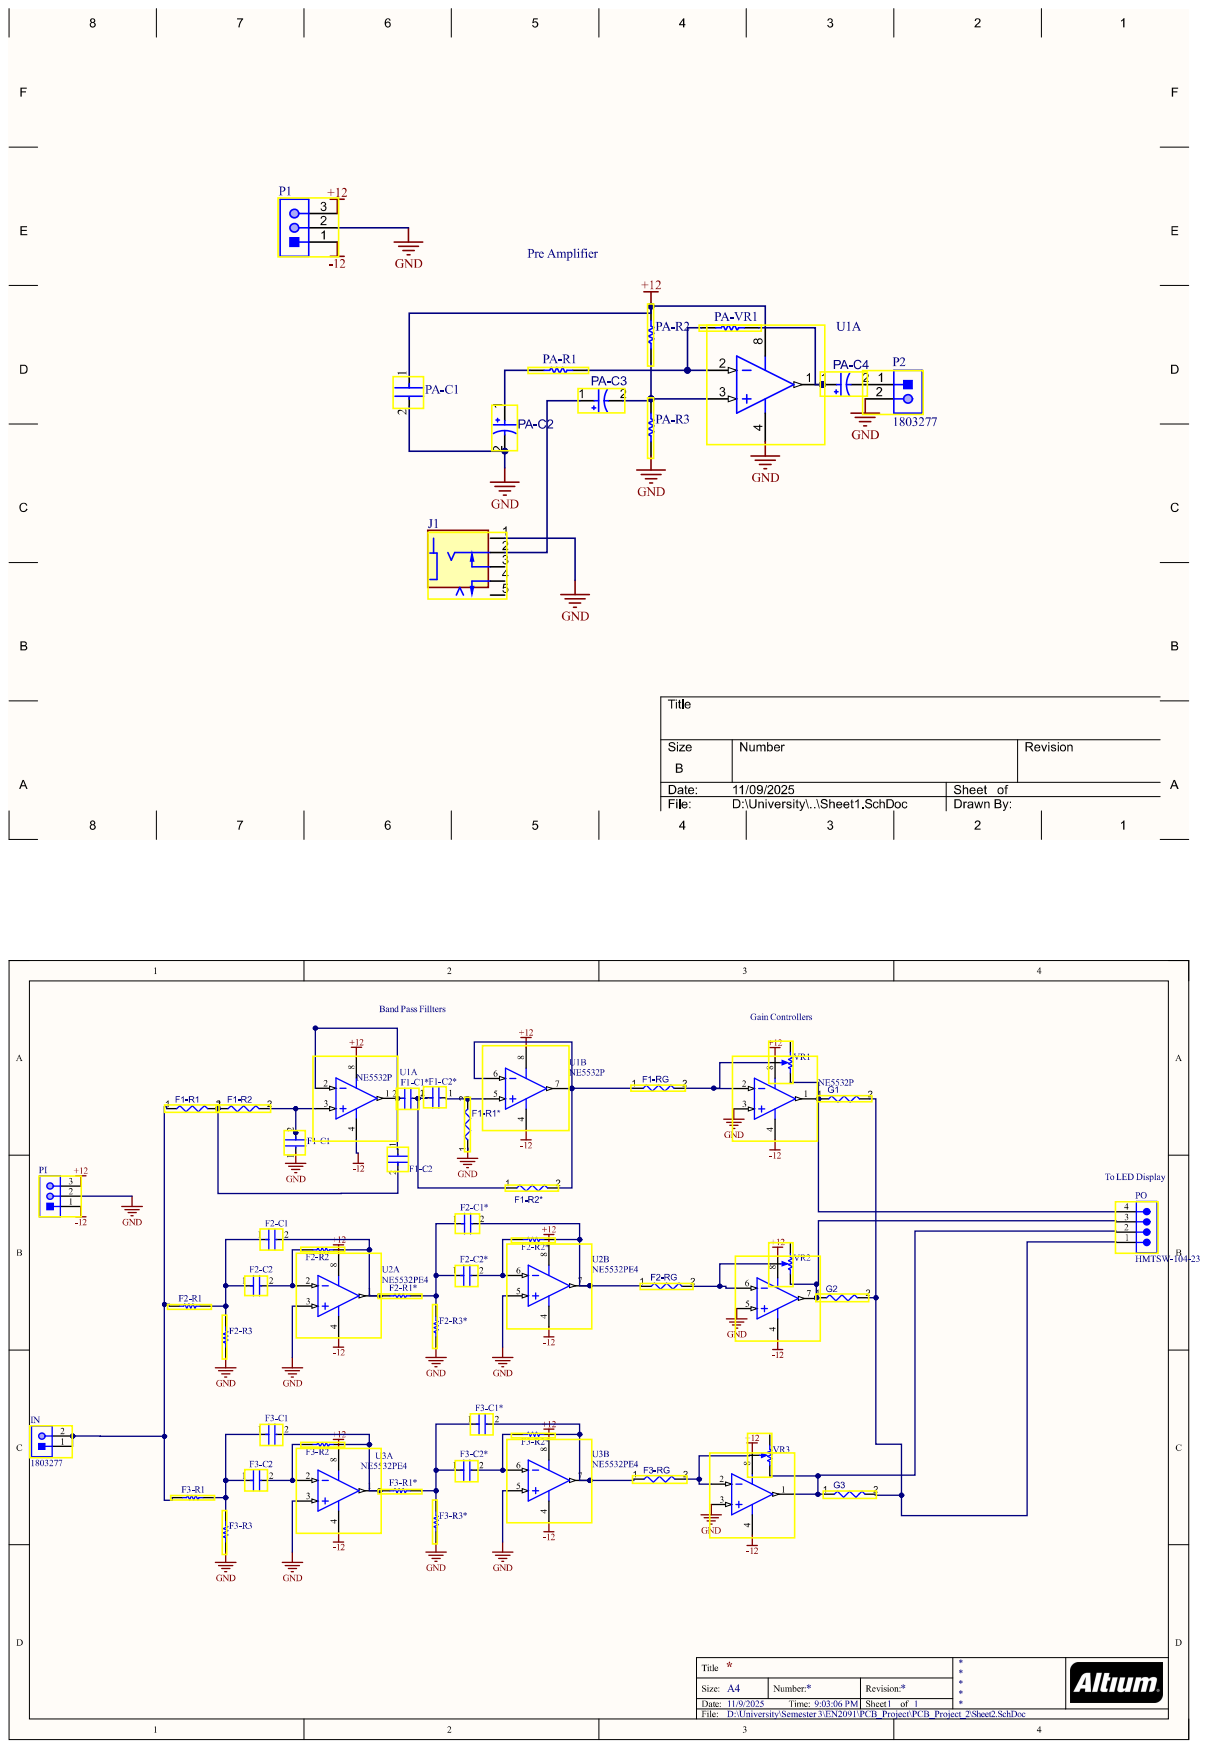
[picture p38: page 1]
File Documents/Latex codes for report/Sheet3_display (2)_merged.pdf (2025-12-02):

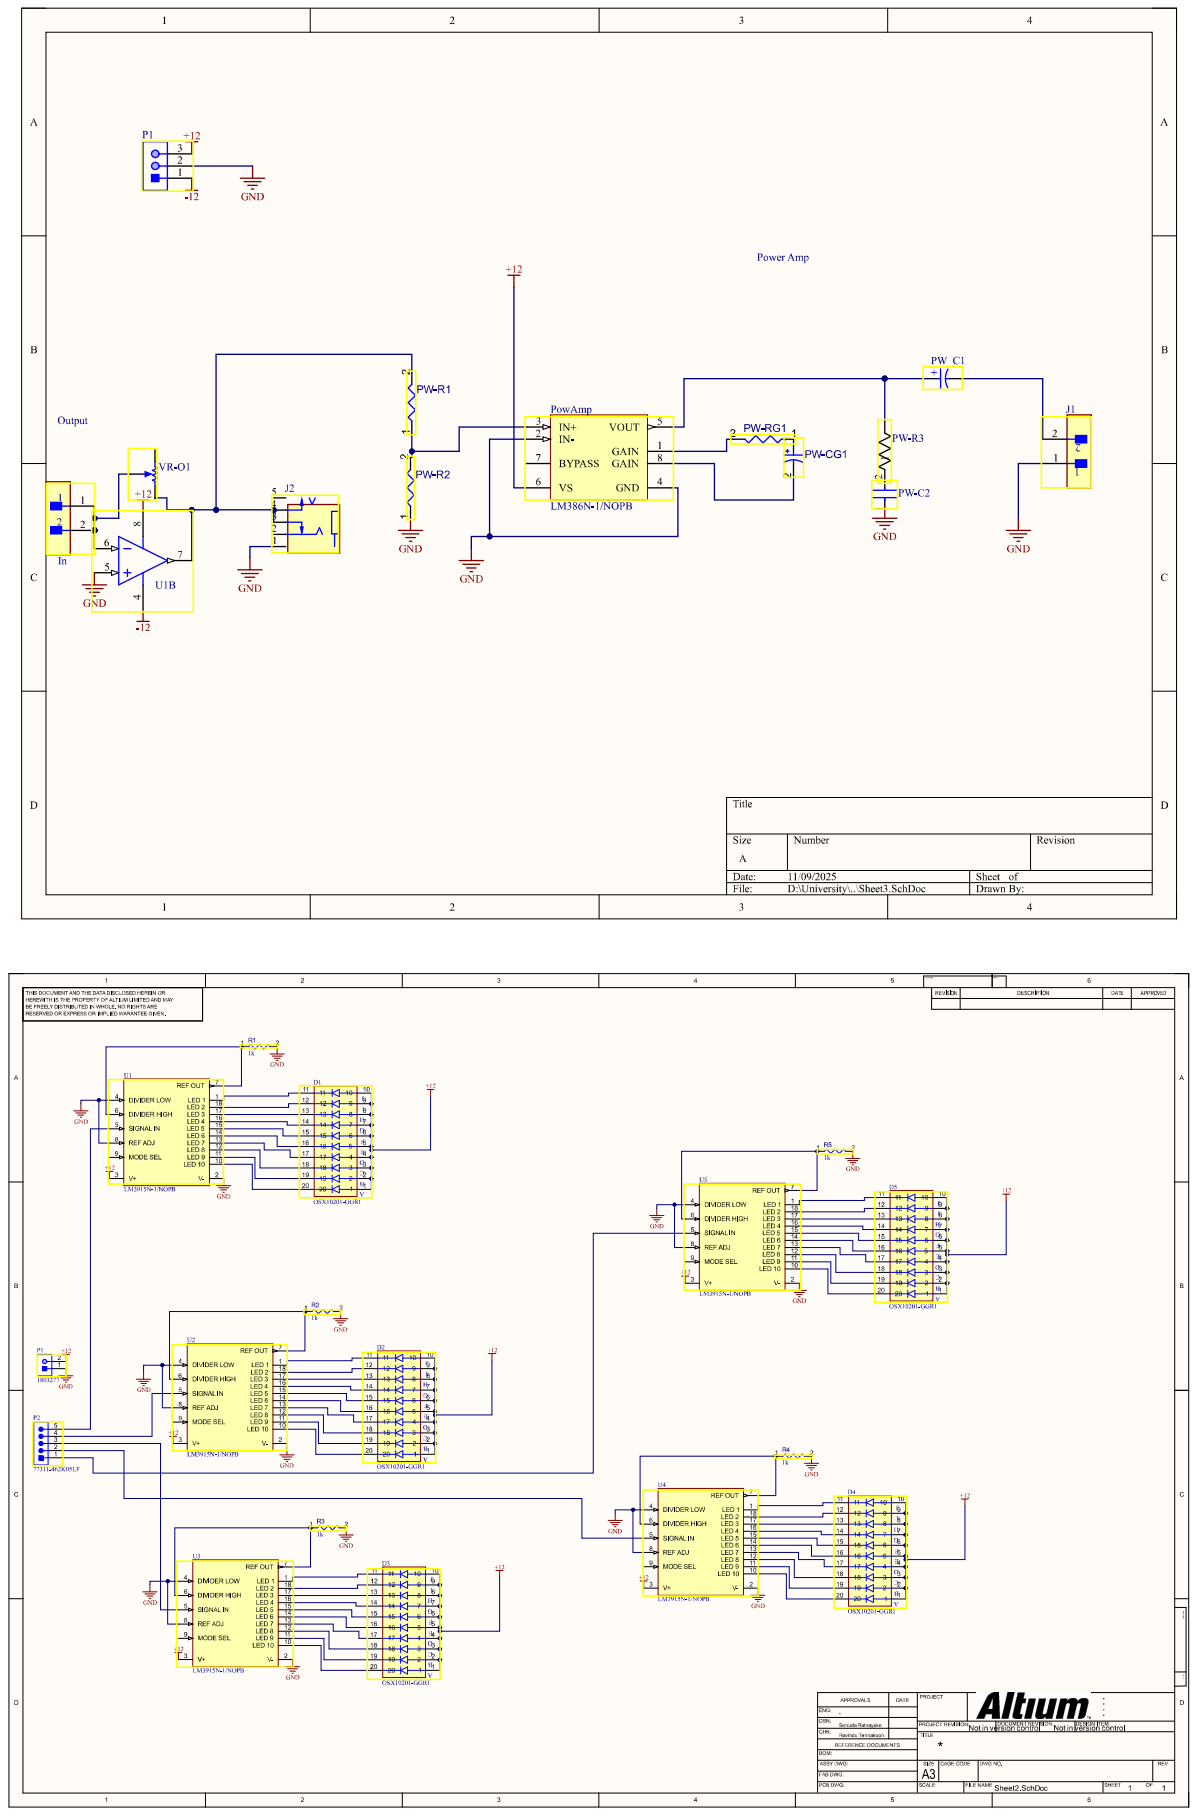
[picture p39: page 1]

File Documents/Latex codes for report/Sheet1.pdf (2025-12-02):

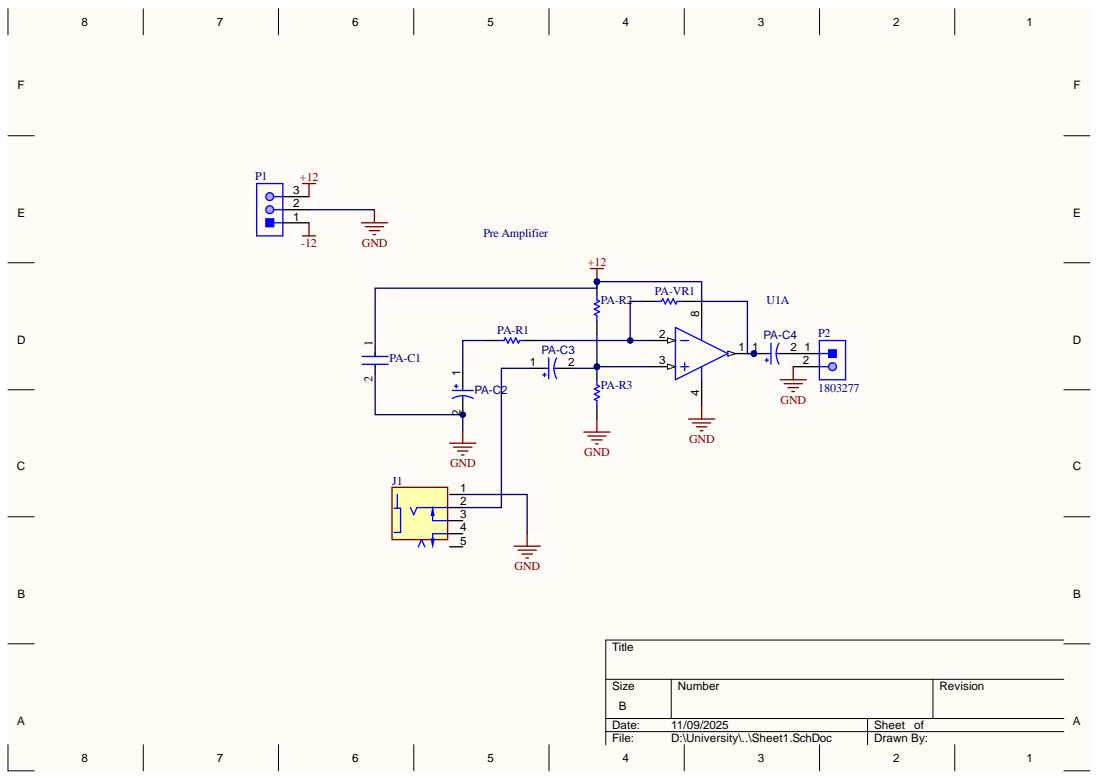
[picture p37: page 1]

Size B | Number | Revision

Date: 11/09/2025 | Sheet of
File: D:\University\..\Sheet1.SchDoc | Drawn By:
